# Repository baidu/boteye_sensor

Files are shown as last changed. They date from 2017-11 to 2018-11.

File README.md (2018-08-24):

boteye

## boteye_sensor ##
This repo contains hardware and firmware of Baidu boteye sensor.
**If you purchase the [hardware from Kinco Automation](http://www.kinco.cn/solution/detail?id=36&type=all)(a third party manufacturer), which is already loaded with the latest firmware, you can skip the following steps.**

## Hardware Introduction

Firmware supports three hardware versions: `XP`, `XP2`, and `XP3`.

## FX3 SDK Installation ##
  In order to compile, you need cypress FX3 sdk (http://www.cypress.com/documentation/software-and-drivers/ez-usb-fx3-software-development-kit).

  Download the sdk here http://www.cypress.com/file/221546

  You can get `fx3_firmware_linux.tar.gz` and `cyusb_linux_1.0.4.tar.gz`, then extract to root directory of this repo.
- Install arm gcc compiler

  ```bash
  sudo apt-get install gcc-arm-none-eabi
  ```

- Make sure your arm compiler is `arm-none-eabi-gcc version 4.8.2`

  ```bash
  arm-none-eabi-gcc --version
  ```
- Install gcc compiler

  ```bash
  sudo apt-get install build-essential
  ```

- Modify SDK config file

  - Configure build type in the file `cyfx3sdk/fw_build/fx3_fw/fx3_build_config.mak`

    Change `CYCONFOPT=fx3_debug` to `CYCONFOPT=fx3_release`

  - Configure the arm compiler info in the file `cyfx3sdk/fw_build/fx3_fw/fx3_armgcc_config.mak`

    Change `LDLIBS += ` section to your lib locations, most likely located in `/usr/arm-linux-gnueabi/lib/libc.a` and `/usr/lib/gcc/arm-none-eabi/4.8.2/libgcc.a`, and replace the default like this:
    ```bash
    The ARM toolchain location and the version are taken from environment variables
    LDLIBS  += \
    /usr/lib/arm-none-eabi/lib/libc.a \
    /usr/lib/gcc/arm-none-eabi/4.8.2/libgcc.a \

    EXEEXT		= elf
    ```
- Compile img format convert tools: `elf2img`

  To convert elf to img file, you need to compile `cyfx3sdk/util/elf2img/elf2img.c`
  ```bash
  cd cyfx3sdk/util/elf2img
  gcc elf2img.c -o elf2img -O3
  ```

## Compile Firmware ##
- If everything is all set, you can run `./build.sh` within `boteye_sensor/firmware`, which generates  `cyfxuvc.img`.

## FX3 Image Download Tool Install ##
- Install `libusb-dev`

  ```bash
  sudo apt-get install libusb-1.0-0-dev
  ```

- Install FX3 tools, please read the README in `./cyusb_linux_1.0.4`.

  ```bash
  cd cyusb_linux_1.0.4
  make
  chmod +x install.sh
  sudo ./install.sh
  ```
- If you find an error `qmake-qt4: command not found`, please install qt4 by running

  ```bash
  sudo apt-get install qt4-dev-tools qt4-doc qt4-qtconfig qt4-demos qt4-designer
  ```
- Add execute premission of `cyusb_linux`
  ```bash
  sudo chmod +x /usr/local/bin/cyusb_linux
  ```

- Add the following two lines to `~/.bashrc`, run `source ~/.bashrc`, and assign `CYUSB_ROOT` to the corresponding file path.

  ```bash
  export CYUSB_ROOT=~/Development/sensor/cyusb_linux_1.0.4/
  export LD_LIBRARY_PATH=/usr/local/lib/
  source ~/.bashrc
  ```
## Image Download ##

  - Use `cyusb_linux` to flash your img file to the board flash. If the sensor has an img on flash, it will
  go into auto-run mode with red LED blinking for 1s. If the sensor doesn't have an img on flash, the red LED will
  be always on.  We can use `./sensor/host_bin/spi_test` to erase the img on flash so that we can download a new one.
  - example: `./sensor/host_bin/spi_test /dev/video0`

## Firmware Tools ##
- There are two tools you can use in `firmware/host_bin`.
  - `spi_test`: erase flash
  - `version_test`: read hardware and software version.
- You can also install `luvcview` or other camera view tools to test the camera. However, you will most likely see green and red ghost images due to the custom formatting of the stereo raw images.

## About Version ##
- Hardware version:
  - You can use command `dmesg` to check USB `Product` attribute, it will show the hardware version.
  - Example: `Baidu_Robotics_vision_XP2`
- Software version:
  - You can also use `dmesg` to check USB `SeriaNumber` attribute, it will show the software version.
  - Example: `V0.3.7-839610e-commit` [version num - commit hash - commit/dirty]

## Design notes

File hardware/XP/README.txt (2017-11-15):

目录结构

├── README.txt
├── BOM                              //元件描述BOM
│   ├── XPCAM 1V1 PCB BOM.xls       //XP副板PCB物料
│   ├── XPIMU 1V1 PCB BOM.xls       //XP主板PCB物料
│
├── PCB file                         //PCB文件（可用DXP打开、编译）
│   ├── XPCAM_1V1.PCBDOC            //XP副板PCB文件
│   ├── XPIMU_1V1.PCBDOC            //XP主板PCB文件
│
├── schematic                        //原理文件（可用DXP打开、编译）
│   ├── XPCAM_1V1                  //XP副板原理图文件
│   │   ├── sch_Camera.SchDoc                 
│   │   ├── XPCAM_1V1.PrjPCB                  
│
│   ├── XPIMU_1V1                  //XP主板原理图文件   
│   │   ├── sch_Connet&IMU.SchDoc                 
│   │   ├── sch_CPU.SchDoc    
│   │   ├── sch_Power.SchDoc                
│   │   ├── sch_Top.SchDoc     
│   │   ├── sch_USB3.0.SchDoc                
│   │   ├── XPIMU_1V1.PrjPCB   
│
├── schematic&PCB PDF                //原理图、PCB的pdf格式
│   ├── PCB                         //XP PCB文件pdf格式
│   │   ├── XPCAM_1V1.pdf                
│   │   ├── XPIMU_1V1.pdf   
│
│   ├── schematic                  //XP 原理图文件pdf格式
│   │   ├── XPCAM_1V1_SCH.pdf                
│   │   ├── XPIMU_1V1_SCH.pdf      
└── 

硬件版本说明：

1.第一版，为主板连接双sensor的形式。

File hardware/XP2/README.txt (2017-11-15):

目录结构

├── README.txt
├── BOM                             //元件描述BOM
│   ├── XPCAM 1V4 PCB BOM.xls       //XP2副板PCB物料
│   ├── XPIAC 1V3 PCB BOM.xls       //XP2板PCB物料
│
├── PCB file                        //PCB文件（可用DXP打开、编译）
│   ├── XPCAM_1V4.PCBDOC            //XP2副板PCB文件
│   ├── XPIAC_1V3.PCBDOC            //XP2主板PCB文件
│
├── schematic                       //原理文件（可用DXP打开、编译）
│   ├── XPCAM_1V4                   //XP2副板原理图文件
│   │   ├── sch_Camera.SchDoc                 
│   │   ├── XPCAM_1V4.PrjPCB                  
│
│   ├── XPIAC_1V3                   //XP2主板原理图文件   
│   │   ├── sch_Camera.SchDoc 
│   │   ├── sch_Connet&IMU.SchDoc                 
│   │   ├── sch_CPU.SchDoc    
│   │   ├── sch_Power.SchDoc                
│   │   ├── sch_Top.SchDoc     
│   │   ├── sch_USB3.0.SchDoc                
│   │   ├── XPIAC_1V3.PrjPCB   
│
├── schematic&PCB PDF               //原理图、PCB的pdf格式
│   ├── PCB                         //XP2 PCB文件pdf格式
│   │   ├── XPCAM_1V4.pdf                
│   │   ├── XPIAC_1V3.pdf   
│
│   ├── schematic                   //XP2 原理图文件pdf格式
│   │   ├── XPCAM_1V4_SCH.pdf                
│   │   ├── XPIAC_1V3_SCH.pdf      
└── 

硬件版本说明：

1.优化XPCAM电源
2.将XPIMU与XPCAM合并为XPIAC
3.兼容彩色跟黑白

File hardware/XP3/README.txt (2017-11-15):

目录结构

├── README.txt
├── BOM                                //元件描述BOM
│   ├── XPCAM-C 1V4 PCB BOM.xls       //XP3副板PCB物料
│   ├── XPIAC-C 1V3 PCB BOM.xls       //XP3主板PCB物料
│
├── PCB file                           //PCB文件（可用DXP打开、编译）
│   ├── XPCAM-C_1V4.PCBDOC            //XP3副板PCB文件
│   ├── XPIAC-C_1V3.PCBDOC            //XP3主板PCB文件
│
├── schematic                          //原理文件（可用DXP打开、编译）
│   ├── XPCAM-C_1V4                    //XP3副板原理图文件
│   │   ├── sch_Camera.SchDoc                 
│   │   ├── XPCAM-C_1V4.PrjPCB                  
│
│   ├── XPIAC-C_1V3                  //XP3主板原理图文件   
│   │   ├── sch_Camera.SchDoc 
│   │   ├── sch_Connet&IMU.SchDoc                 
│   │   ├── sch_CPU.SchDoc    
│   │   ├── sch_Power.SchDoc                
│   │   ├── sch_Top.SchDoc     
│   │   ├── sch_USB3.0.SchDoc                
│   │   ├── XPIAC-C_1V3.PrjPCB   
│
├── schematic&PCB PDF                //原理图、PCB的pdf格式
│   ├── PCB                         //XP3 PCB文件pdf格式
│   │   ├── XPCAM-C_1V4.pdf                
│   │   ├── XPIAC-C_1V3.pdf   
│
│   ├── schematic                  //XP3 原理图文件pdf格式
│   │   ├── XPCAM-C_1V4_SCH.pdf                
│   │   ├── XPIAC-C_1V3_SCH.pdf      
└── 

硬件版本说明：

1.优化XPCAM电源
2.将XPIMU与XPCAM合并为XPIAC
3.兼容彩色跟黑白

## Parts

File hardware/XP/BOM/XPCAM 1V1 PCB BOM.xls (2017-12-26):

电子产品零件表
 |  | 版本:XPCAM 1V1 PCB BOM V1.0
序号 | 物料代码 | 数量 | 元件位置 | 规格 | 用途 | 备注
1 | 4.2.03.0089 | 3 | C16,C17,C18 | 贴片电容 10nF/0402/50V/10% | PCB
2 | 4.2.03.0088 | 14 | C2,C3,C4,C7,C8, C11,C12,C15,C19,C20, C21,C25,C26,C36 | 贴片电容 0.1uF/0402/16V/10% | PCB
3 | 4.2.03.0096 | 7 | C5,C9,C13,C23,C27, C34,C42 | 贴片电容 1uF/0402/6.3V/10% | PCB
4 | 4.2.03.0095 | 4 | C6,C10,C14,C45 | 贴片电容 4.7uF/0402/6.3V/20% | PCB
5 | 4.2.03.0101 | 7 | C1,C24,C28,C31,C35, C43,C44 | 贴片电容 10uF/0805/25V/10% | PCB
6 | 4.2.02.0205 | 1 | R7 | 贴片电阻 0R/0402/1% | PCB
7 | 4.2.02.0220 | 1 | R3 | 贴片电阻 22R/0402/5% | PCB
8 | 4.2.02.0214 | 5 | R1,R2,R4,R5,R6 | 贴片电阻 10K/0402/1% | PCB
9 | 7.2.01.0411 | 3 | U2,U3,U4 | 降压芯片 TPS73533DRVR | PCB
10 | 7.2.01.0412 | 1 | U1 | 集成芯片 MT9V024IA7XTM | PCB
11 | 7.2.07.0382 | 1 | J1 | 接插端子 20525-030E-02 | PCB
12 | 7.2.06.0203 | 1 |  | PCB光板 | PCB

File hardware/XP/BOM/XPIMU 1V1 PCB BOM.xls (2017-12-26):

电子产品零件表
 |  | 版本:XPIMU 1V1 PCB BOM V1.0
料号 | 物料代码 | 数量 | 元件位置 | 规格 | 用途 | 备注
1 | 7.2.03.0153 | 2 | C49,C50 | 贴片电容 12pF/0402/50V/5% | PCB
2 | 4.2.03.0089 | 12 | C13,C16,C17,C22,C25, C27,C28,C94,C95,C96, C97,C98 | 贴片电容 10nF/0402/50V/10% | PCB
3 | 4.2.03.0088 | 34 | C1,C3,C4,C5,C6, C7,C8,C9,C10,C11, C12,C14,C15,C19,C21, C23,C24,C26,C29,C31, C33,C35,C37,C39,C40, C41,C42,C51,C52,C53, C54,C58,C59,C67 | 贴片电容 0.1uF/0402/16V/10% | PCB
4 | 7.2.03.0146 | 1 | C57 | 贴片电容 0.47uF/0402/6.3V/10% | PCB
5 | 4.2.03.0096 | 1 | C60 | 贴片电容 1uF/0402/6.3V/10% | PCB
6 | 4.2.03.0095 | 3 | C36,C55,C56 | 贴片电容 4.7uF/0402/6.3V/20% | PCB
7 | 7.2.03.0154 | 1 | C32 | 贴片电容 4.7uF/0805/25V/10% | PCB
8 | 4.2.03.0101 | 2 | C34,C43 | 贴片电容 10uF/0805/25V/10% | PCB
9 | 7.2.03.0144 | 4 | C2,C18,C20,C30 | 贴片电容 47uF/0805/6.3V/20% | PCB
10 | 4.2.02.0205 | 2 | R30,R57 | 贴片电阻 0R/0402/1% | PCB
11 | 4.2.02.0220 | 3 | R27,R34,R60 | 贴片电阻 22R/0402/5% | PCB
12 | 4.2.02.0208 | 2 | R6,R21 | 贴片电阻 200R/0402/1% | PCB
13 | 4.2.02.0218 | 6 | R5,R14,R58,R59,R67, R62 | 贴片电阻 1K/0402/1% | PCB
14 | 4.2.02.0209 | 1 | R18 | 贴片电阻 1.5K/0402/1% | PCB
15 | 4.2.02.0226 | 2 | R25,R26 | 贴片电阻 2.2K/0402/5% | PCB
16 | 4.2.02.0210 | 1 | R20 | 贴片电阻 6.04K/0402/1% | PCB
17 | 4.2.02.0217 | 20 | R1,R2,R3,R7,R8, R10,R11,R12,R15,R16, R17,R19,R28,R29,R31, R32,R33,R35,R36,R37 | 贴片电阻 4.7K/0402/1% | PCB
18 | 4.2.02.0214 | 3 | R9,R44，R63 | 贴片电阻 10K/0402/1% | PCB
19 | 4.2.02.0213 | 1 | R53 | 贴片电阻 30.1K/0402/1% | PCB
20 | 4.2.02.0233 | 3 | R4,R13,R56 | 贴片电阻 100K/0402/1% | PCB
21 | 7.2.05.0130 | 1 | LED1, | 发光二极管 红色/0805 | PCB
22 | 7.2.05.0123 | 2 | LED2,LED3 | 发光二极管 绿色/0805 | PCB
23 | 4.2.04.0507 | 3 | FB1,FB2,FB3 | 磁珠 600@100MHz | PCB
24 | 7.2.08.0222 | 1 | U14 | 27M晶振 XTAL-3225 | PCB
25 | 7.2.08.0223 | 1 | U7 | 32.768K晶振 XTAL-3225 | PCB
26 | 7.2.08.0224 | 1 | Y1 | 19.2M晶振 XTAL_3225 | PCB
27 | 7.2.01.0413 | 1 | U9 | 陀螺仪芯片 ICM-20608-G | PCB
28 | 7.2.01.0414 | 1 | U13 | 降压芯片 AS1364-BTDT-AD | PCB
29 | 7.2.05.1005 | 3 | Q1,Q2,Q3 | NPN三极管 BC817 | PCB
30 | 7.2.08.0049 | 1 | U6 | 贴片保险丝 SP3010-04UTG | PCB
31 | 7.2.01.0415 | 1 | U4 | 降压芯片TPS74801DRCR | PCB
32 | 7.2.01.0416 | 1 | U2 | EEPROM芯片 M25P40-VMN3TPB | PCB
33 | 7.2.01.0417 | 1 | U1 | USB控制器 CYUSB3014 | PCB
34 | 7.2.07.1069 | 1 | J1 | USB3.0插头USB3_MICROB | PCB
35 | 7.2.07.0382 | 2 | J5,J6 | 接插端子 20525-030E-02C | PCB
36 | 7.2.06.0204 | 1 |  | PCB光板 | PCB

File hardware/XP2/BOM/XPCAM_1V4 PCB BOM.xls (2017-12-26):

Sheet: Read me
删除R38,C65更改为4.2.03.0095

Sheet: 170504
电子产品零件表
 |  | 版本:XPCAM 1V4 PCB BOM V1.0
序号 | 物料代码 | 数量 | 元件位置 | 元件描述 | 用途 | 备注
1 | 4.2.03.0104 | 1 | C85 | 贴片电容 1nF/0402/50V/10% | PCB
2 | 4.2.03.0089 | 2 | C81,C84 | 贴片电容 10nF/0402/50V/10% | PCB
3 | 4.2.03.0088 | 10 | C46,C47,C48,C61,C62, C66,C77,C78,C82,C83 | 贴片电容 0.1uF/0402/16V/10% | PCB
4 | 4.2.03.0095 | 7 | C44,C52,C63,C65,C70,C76, C79 | 贴片电容 4.7uF/0402/6.3V/20% | PCB
5 | 4.2.03.0101 | 4 | C39,C45,C64,C71 | 贴片电容 10uF/0805/25V/10% | PCB
6 | 4.2.02.0220 | 1 | R24 | 贴片电阻 22R/0402/5% | PCB
7 | 4.2.02.0214 | 5 | R23,R39,R40,R41,R42 | 贴片电阻 10K/0402/1% | PCB
8 | 7.2.04.0005 | 1 | L1 | 贴片电感 10uH/0805/10% | PCB
9 | 7.2.01.0411 | 1 | U5 | 降压芯片 TPS73533DRVR | PCB
10 | 7.2.01.0412 | 1 | U1 | 集成芯片 MT9V024IA7XTM | PCB
11 | 7.2.07.0382 | 1 | J1 | 接插端子 20525-030E-02 | PCB
12 | 7.2.06.0224 | 1 |  | PCB光板 | PCB

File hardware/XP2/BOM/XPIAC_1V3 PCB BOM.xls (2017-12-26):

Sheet: Read me
更改说明

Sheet: 171017
电子产品零件表
 |  | 版本:XPIAC 1V3 PCB BOM V1.0
料号 | 物料代码 | 数量 | 元件位置 | 元件描述 | 用途 | 备注
1 | 4.2.03.0104 | 1 | C85 | 贴片电容 1nF/0402/50V/10% | PCB
2 | 7.2.03.0153 | 2 | C49,C50 | 贴片电容 12pF/0402/50V/5% | PCB
3 | 4.2.03.0089 | 10 | C13,C16,C17,C22,C27, C81,C94,C95,C97,C98 | 贴片电容 10nF/0402/50V/10% | PCB
4 | 4.2.03.0088 | 40 | C1,C3,C4,C5,C6,C7, C8,C9,C10,C11,C12, C14,C15,C19,C21,C23, C24,C26,C29,C31,C33, C35,C37,C40,C41,C42, C46,C48,C51,C53,C58, C59,C61,C66,C68,C69, C77,C78,C82,C86 | 贴片电容 0.1uF/0402/16V/10% | PCB
5 | 7.2.03.0146 | 1 | C57 | 贴片电容 0.47uF/0402/6.3V/10% | PCB
6 | 4.2.03.0095 | 13 | C25,C28,C36,C44,C52, C54,C55,C56,C60,C63, C70,C76,C79 | 贴片电容 4.7uF/0402/6.3V/20% | PCB
7 | 4.2.03.0101 | 6 | C32,C34,C39,C43,C45, C64 | 贴片电容 10uF/0805/25V/10% | PCB
8 | 4.2.03.0094 | 4 | C2,C18,C20,C30 | 贴片电容 47uF/0805/6.3V/20% | PCB
9 | 7.2.04.0086 | 1 | L2 | 贴片电感 100uH/600mA | PCB
10 | 7.2.04.0005 | 1 | L1 | 贴片电感 10uH/0805 | PCB
11 | 4.2.02.0205 | 2 | R30,R57 | 贴片电阻 0R/0402/1% | PCB
12 | 4.2.02.0220 | 4 | R22,R24,R27,R60 | 贴片电阻 22R/0402/5% | PCB
13 | 4.2.02.0208 | 2 | R6,R21 | 贴片电阻 200R/0402/1% | PCB
14 | 4.2.02.0218 | 7 | R5,R14,R58,R59,R62, R63,R67 | 贴片电阻 1K/0402/1% | PCB
15 | 4.2.02.0209 | 1 | R18 | 贴片电阻 1.5K/0402/1% | PCB
16 | 4.2.02.0226 | 2 | R25,R26 | 贴片电阻 2.2K/0402/5% | PCB
17 | 4.2.02.0210 | 1 | R20 | 贴片电阻 6.04K/0402/1% | PCB
18 | 4.2.02.0217 | 12 | R1,R2,R3,R11,R12, R15,R16,R17,R19,R29, R31,R32 | 贴片电阻 4.7K/0402/1% | PCB
19 | 4.2.02.0214 | 7 | R9,R23,R39,R40,R41, R42,R44 | 贴片电阻 10K/0402/1% | PCB
20 | 4.2.02.0213 | 1 | R53 | 贴片电阻 30.1K/0402/1% | PCB
21 | 4.2.02.0233 | 3 | R4,R13,R56 | 贴片电阻 100K/0402/1% | PCB
22 | 7.2.05.0130 | 1 | LED1 | 发光二极管 红色/0805 | PCB
23 | 4.2.04.0507 | 3 | FB1,FB2,FB3 | 磁珠 600@100MHz | PCB
24 | 7.2.08.0222 | 1 | Y2 | 27M晶振 XTAL-3225 | PCB
25 | 7.2.08.0223 | 1 | U7 | 32.768K晶振 XTAL-3225 | PCB
26 | 7.2.08.0224 | 1 | Y1 | 19.2M晶振 XTAL_3225 | PCB
27 | 7.2.01.0413 | 1 | U9 | 陀螺仪芯片 ICM-20608-G | PCB
28 | 7.2.01.0414 | 1 | U13 | 降压芯片 AS1364-BTDT-AD | PCB
29 | 7.2.05.1005 | 4 | Q1,Q2,Q3,Q4 | NPN三极管 BC817 | PCB
30 | 7.2.08.0139 | 2 | S1,S2 | 贴片按键 2P | PCB
31 | 7.2.08.0049 | 1 | U6 | 贴片保险丝 SP3010-04UTG | PCB
32 | 7.2.01.0415 | 1 | U4 | 降压芯片 TPS74801DRCR | PCB
33 | 7.2.01.0416 | 1 | U2 | EEPROM芯片 M25P40-VMN3TPB | PCB
34 | 7.2.01.0417 | 1 | U1 | USB控制器 CYUSB3014 | PCB
35 | 7.2.07.1076 | 1 | J1 | USB3.0插头USB3_MICROB | PCB
36 | 7.2.07.0192 | 1 | P1 | uart接插端子 A1252MV-04P | PCB
37 | 7.2.07.0382 | 1 | J6 | 接插端子 20525-030E-02C | PCB
38 | 7.2.01.0411 | 1 | U5 | 降压芯片 TPS73533DRVR | PCB
39 | 7.2.01.0412 | 1 | U8 | 集成芯片 MT9V024IA7XTM | PCB
40 | 7.2.06.0236 | 1 |  | PCB光板 | PCB

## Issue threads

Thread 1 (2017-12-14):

可以把 GPIF II 工程代码也上传吗

cudnn, 2017-12-14:
我看了固件里 cyfxgpif2config.h 文件修改很多，能把 GPIF II 的有关文件也上传吗？

zhouryGitHub, 2017-12-19:
Our project is modified based on old version of  sample code cyfxuvc.  Now I am working to sync latest version . after finish it . gprif II file will upload.

cudnn, 2018-01-05:
Thanks very much! 你能看懂中文啊，太好了！我看了pcb布线也有一点疑问，XP2之后，fx3与mt9v034之间的信号使用了很多蛇形布线，这是不是为了实现信号线的等长？如果是，那么两个摄像头到fx3的距离也要等长吧？因为他们使用同一个时钟！所以还是建议两个摄像头分别做，并且时钟发生器放买主板上，到两点摄像头的距离也等长！

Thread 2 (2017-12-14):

GPIF II  project is  missing

cudnn, 2017-12-14:
When I try to load the GPIF II designer file,i find ImageSensorInterface.cyfx and gpif2model.xml gpif2timingsimulation.xml gpif2view.xml is  missing 。

zhouryGitHub, 2017-12-19:
Our project is modified based on old version of  sample code cyfxuvc.  Now I am working to sync latest version . After finish it . gprif II file will upload.

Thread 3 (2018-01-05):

cmos和fx3布线的疑问

cudnn, 2018-01-05:
我看了pcb布线也有一点疑问，XP2之后，fx3与mt9v034之间的信号使用了很多蛇形布线，这是不是为了实现信号线的等长？如果是，那么两个摄像头到fx3的距离也要等长吧？因为他们使用同一个时钟！所以还是建议两个摄像头分别做，并且时钟发生器放买主板上，到两点摄像头的距离也等长！

qinzengpan, 2018-01-05:
是实现等长。是否分开设计与性能要求、场景应用有关、制作成本等因素有关。你所说的，理论上对性能要求高的是可以到达更好的效果。但在结构设计上增加了复杂性以及在连接器上你要考虑使用怎么样的连接器和线的材料。所以最终如何设计，是综合考虑，就看你更在乎哪一点。

cudnn, 2018-01-11:
如果不分开，两个摄像头到主控的距离肯定不等长啊。因为使用一个时钟，所以两个摄像头到主控也应该是等长才行啊

qinzengpan, 2018-01-19:
由于板子尺寸、器件的密集型，对布局布线都会带来挑战性，我们的设计是尽量实现等长。及时没有使双目到主控芯片等长，在一些要求不高的场合也是可以允许的。当然，双目到主控的距离实现等长效果最好，你的观点也是没错的。

cudnn, 2018-01-29:
这个项目很好，持续关注中。

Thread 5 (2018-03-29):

为什么两个摄像头使用了两个晶振，不是应该共用一个时钟吗

cudnn, 2018-03-29:

zhouryGitHub, 2018-03-29:
请仔细看原理图，两个摄像头是用的同一个晶振

cudnn, 2018-03-30:
老师 有没有qq 微信啥的加个好友呗 weichat ardupilot4 qq 978917153

cudnn, 2018-03-30:
我再看看

cudnn, 2018-03-30:
我认真看了一， xp3版本中，在主板camera电路上有一个Y2 元件 hso531s 27MHZ，在独立的摄像头板也有一个    hso531s 27MHZ

zhouryGitHub, 2018-04-22:
在XP3 上 双目是共用一个 27M 晶振

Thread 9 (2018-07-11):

cyusb_linux Problem: No device found

VincentHFZ, 2018-07-11:
Try to use cyusb_linux tool to download img file, but the cyusb_linux tool can not find the device

zhouryGitHub, 2018-09-18:
please use ./spi_test to earse the flash on sensor, then you can download  the firmware use cyusb_linux

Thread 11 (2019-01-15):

firmware update problem

johnjin404, 2019-01-15:
你好，我在配置boteye标准版相机驱动时遇到了一些问题，发现它提示需要升级固件（当时检测到的版本是XP2S，在/dev/video1），后来我按照你们给出的提示在这里升级固件，但是这期间遇到两个我目前解决不了的问题。
1、我执行了 Image Download [https://github.com/baidu/boteye_sensor#image-download](url)之前的步骤，没有什么问题，但是在Image Download这步中，只有用命令`./spi_test  /dev/video1  E`没有错误反馈，但是l也没有led灯亮或者闪一秒。因为它没有错误反馈，我就接着执行下面的 version_test 程序，我的命令是`./version_test  /dev/video1`，它好像提示说Buffer size does not match control size。主要是搞不懂这两个程序的运行格式，希望有一个help功能。
2、后来我无意地把连接相机那一端的线拔了，再插上时，里面红灯一直亮着，而且现在/dev/video1也没有了，只剩下电脑自带的/dev/video0，请问怎样才能修复这个？谢谢

HansomHu, 2019-01-15:
问题1，update firmware请参考链接[https://github.com/baidu/boteye_sensor](url)，执行命令`./spi_test /dev/video*`的作用是擦除boteye的firmware，此时已经无法读取版本号，需要重新插拔usb数据线，然后运行`cyusb_linux`烧写新的firmware。
问题2，红灯一直亮，是因为firmware已经被擦除，pc自然检测不到这个video设备。
补充，更新完firmware后，可以通过`dmesg`命令看到boteye的信息，包括版本号。

johnjin404, 2019-01-15:
非常感谢！

Closed 2019-01-15.

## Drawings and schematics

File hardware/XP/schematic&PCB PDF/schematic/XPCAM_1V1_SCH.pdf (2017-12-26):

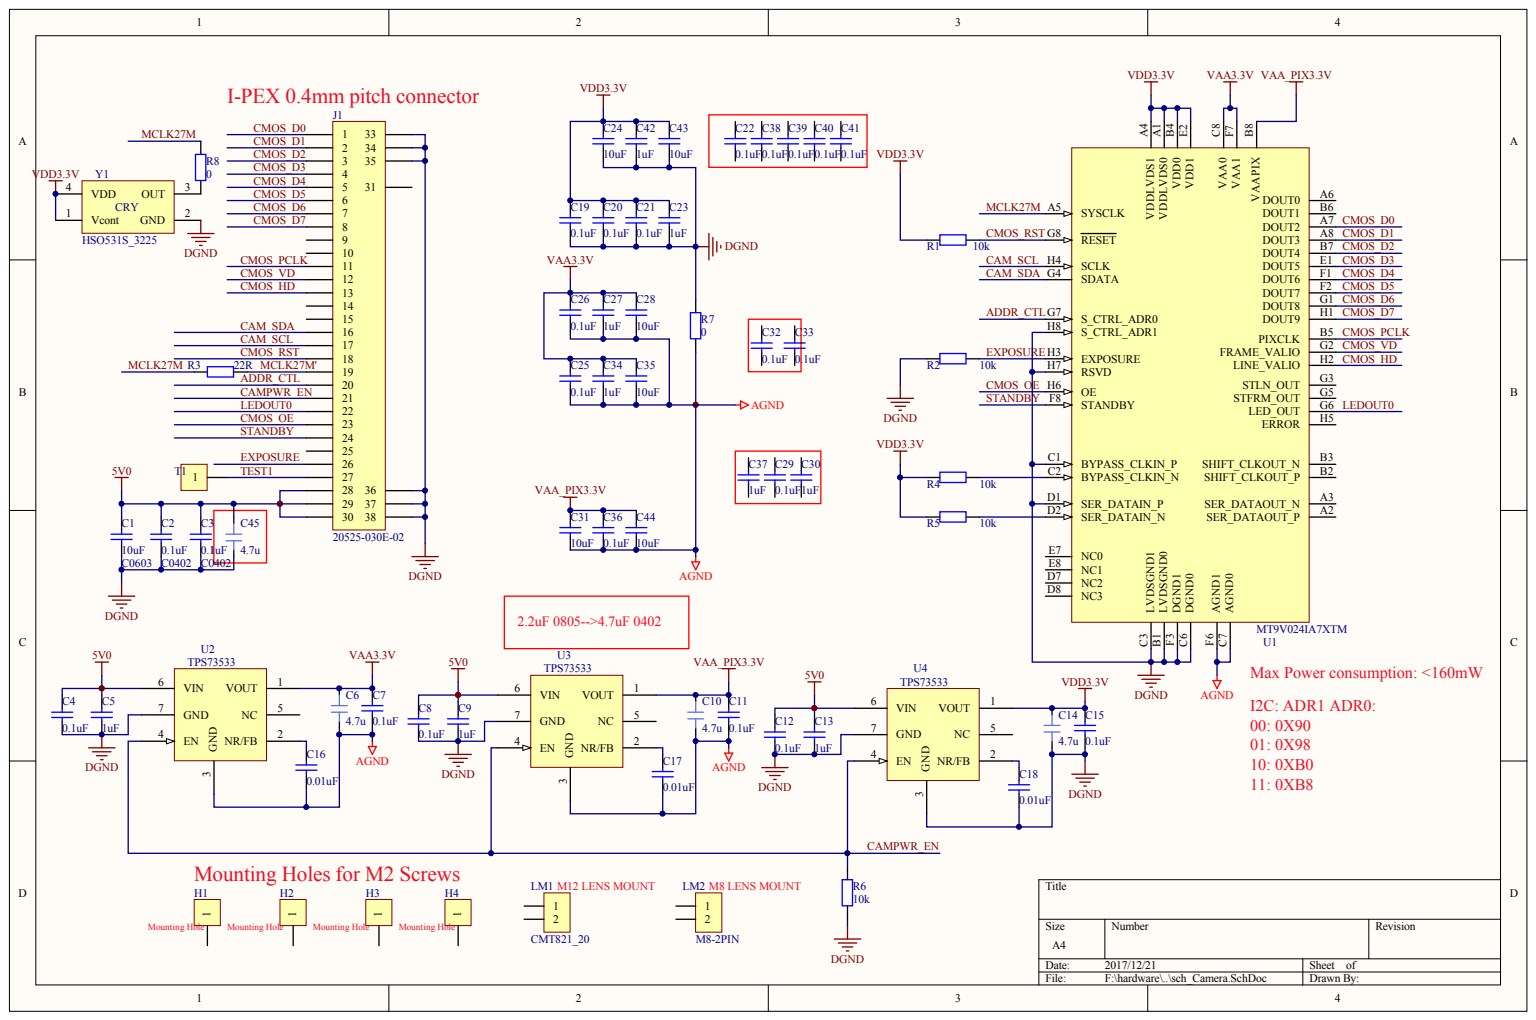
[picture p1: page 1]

Mounting Holes for M2 Screws

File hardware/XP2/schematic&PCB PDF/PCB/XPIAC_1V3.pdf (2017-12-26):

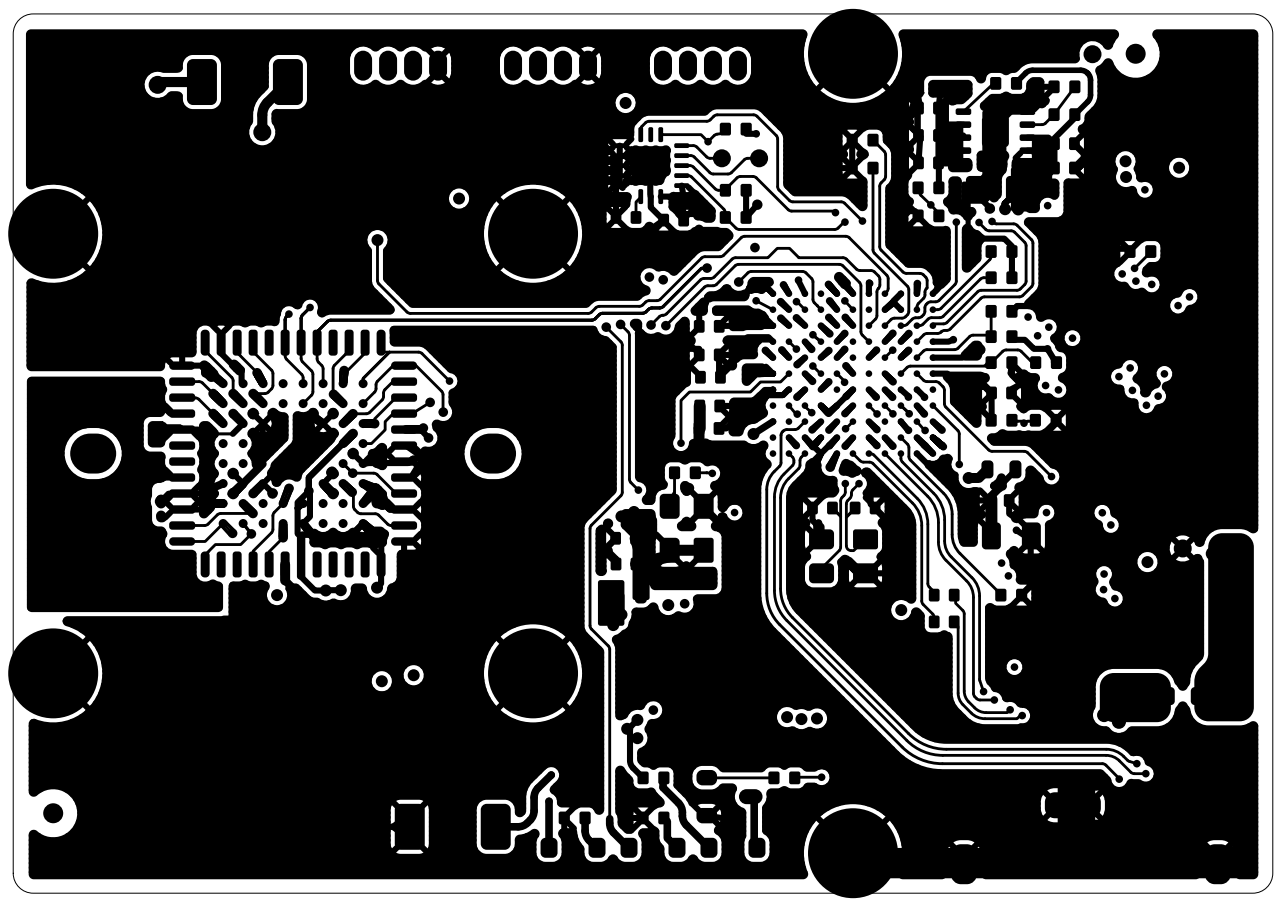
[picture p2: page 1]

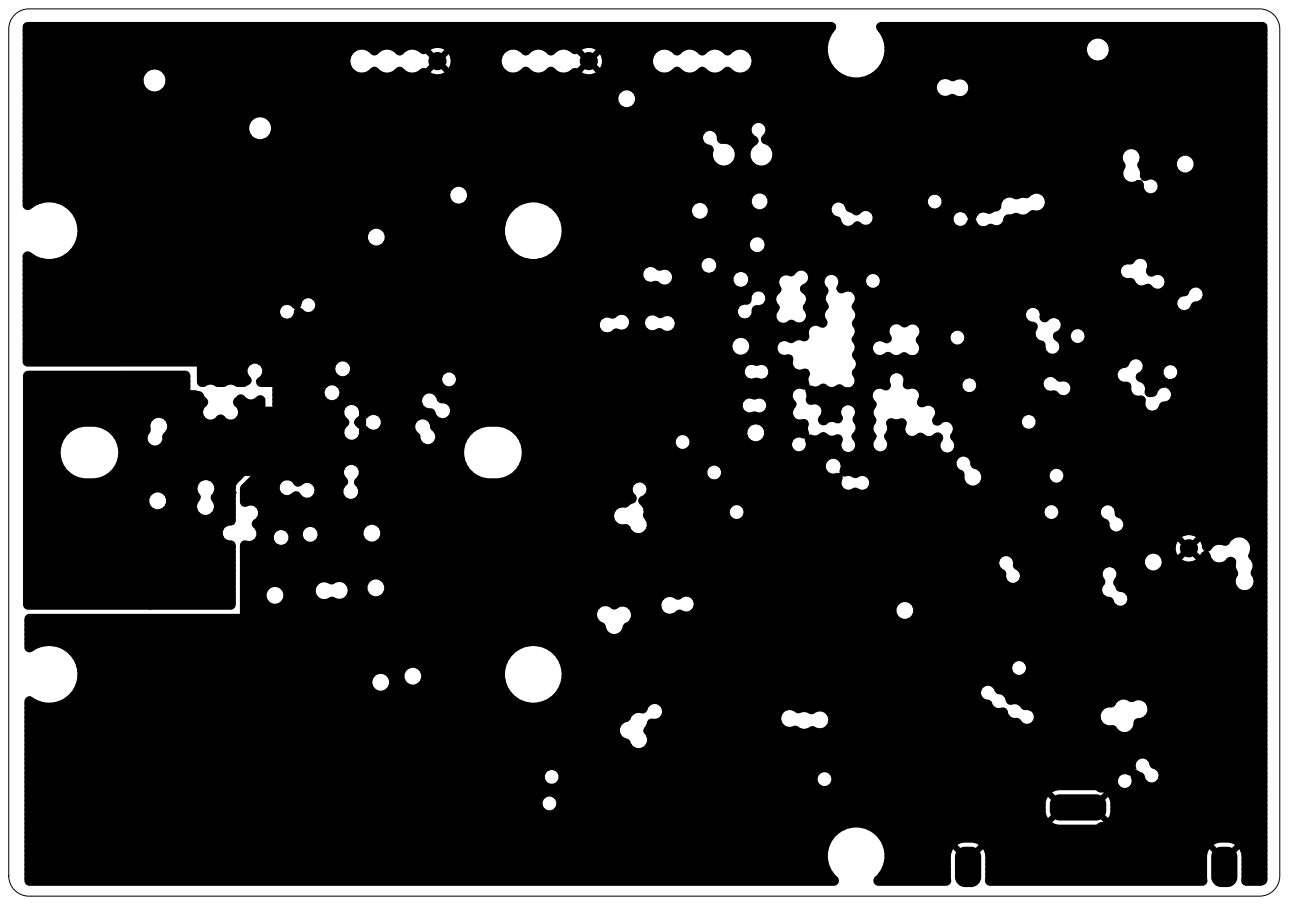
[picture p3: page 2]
H6H⁶x1; H4H⁴x1; GNDGNDx1; H1H¹x1; H2H²x1; H5H⁵x1; H3H³x1; 5V05V⁰x1; P1P¹x1 P¹x2 P¹x3 P¹x4; P2 P3P³x1 P³x2 P³x3 P³x4; P²x1 P²x2 P²x3 P²x4

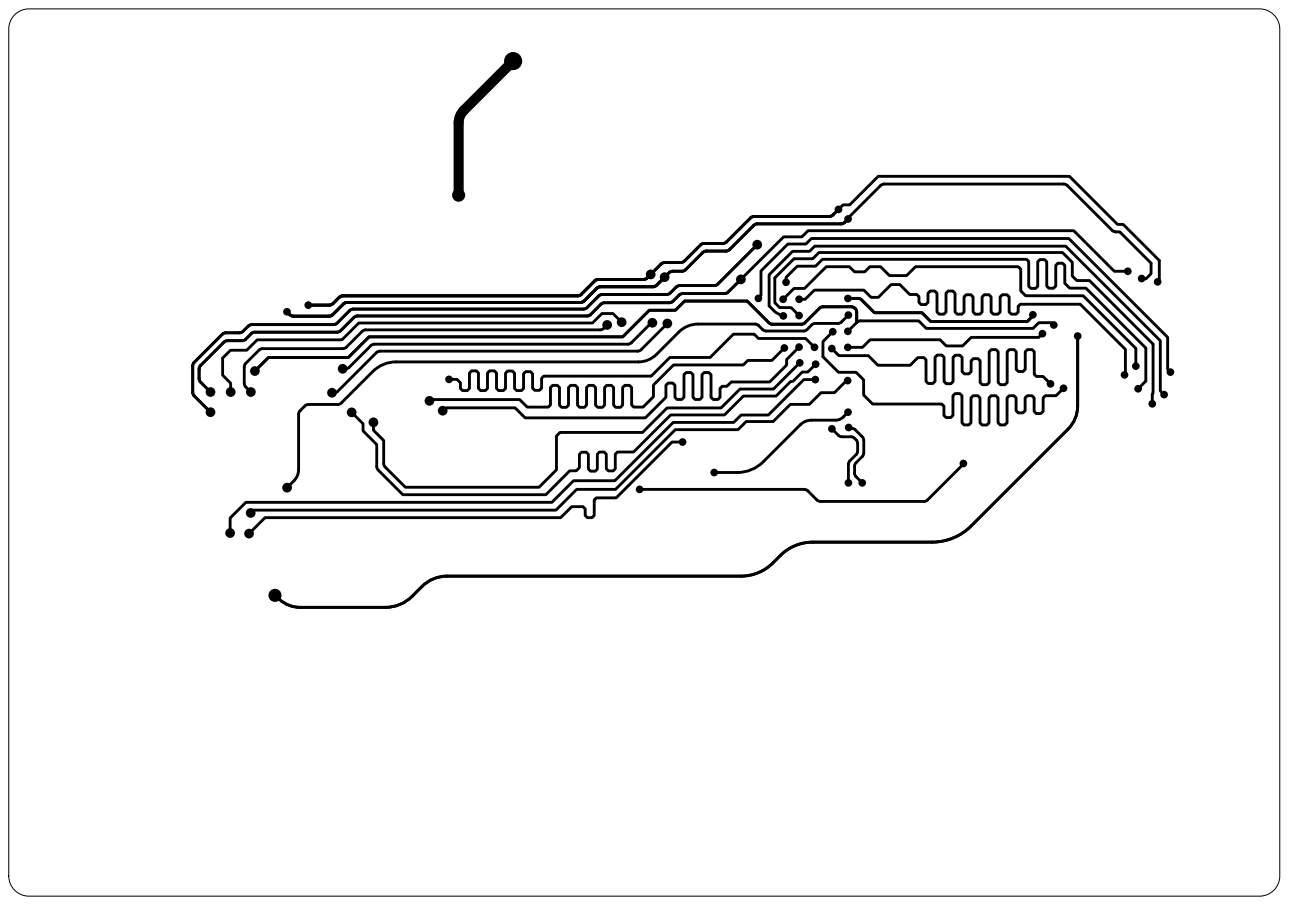
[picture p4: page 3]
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

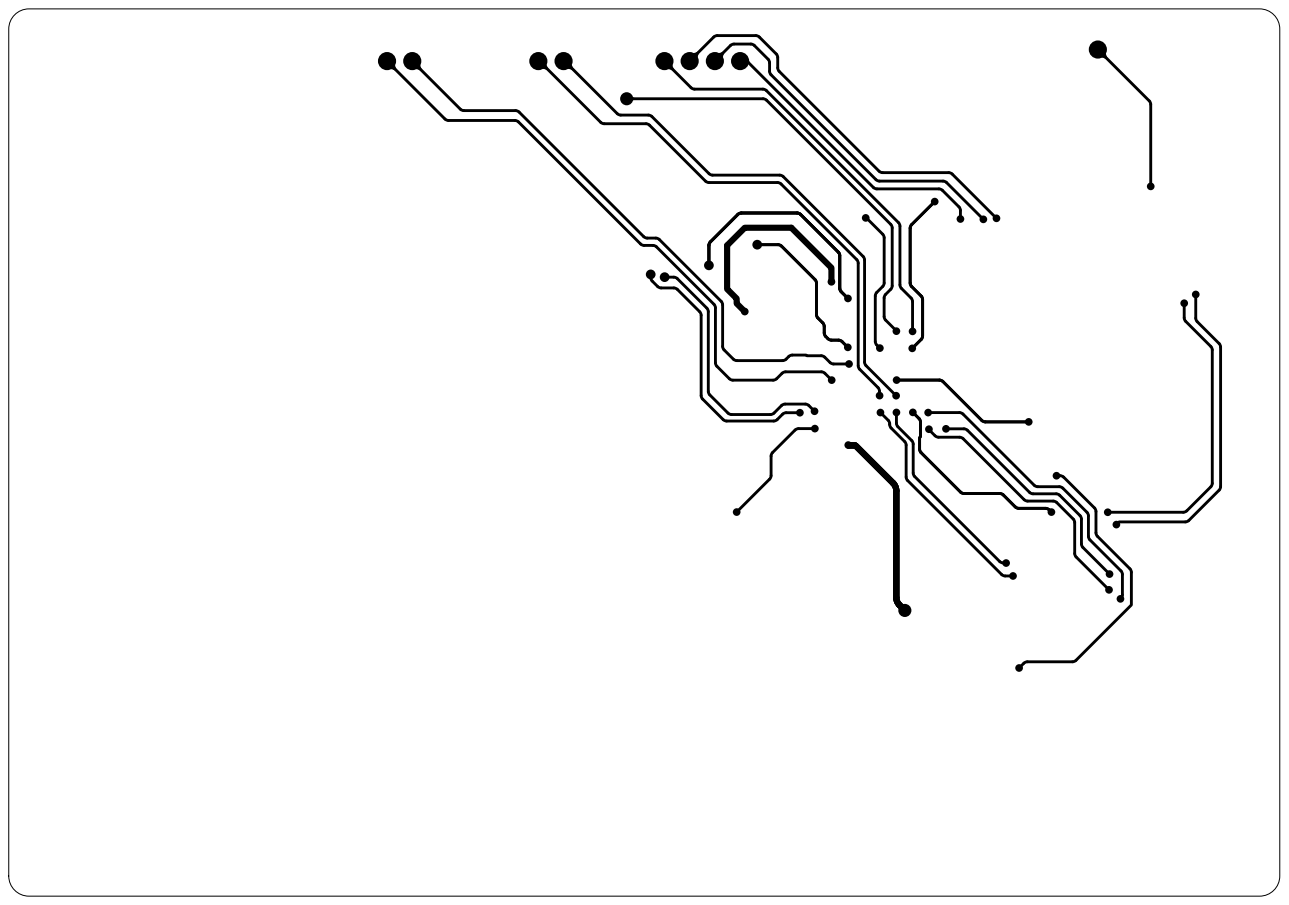
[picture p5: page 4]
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

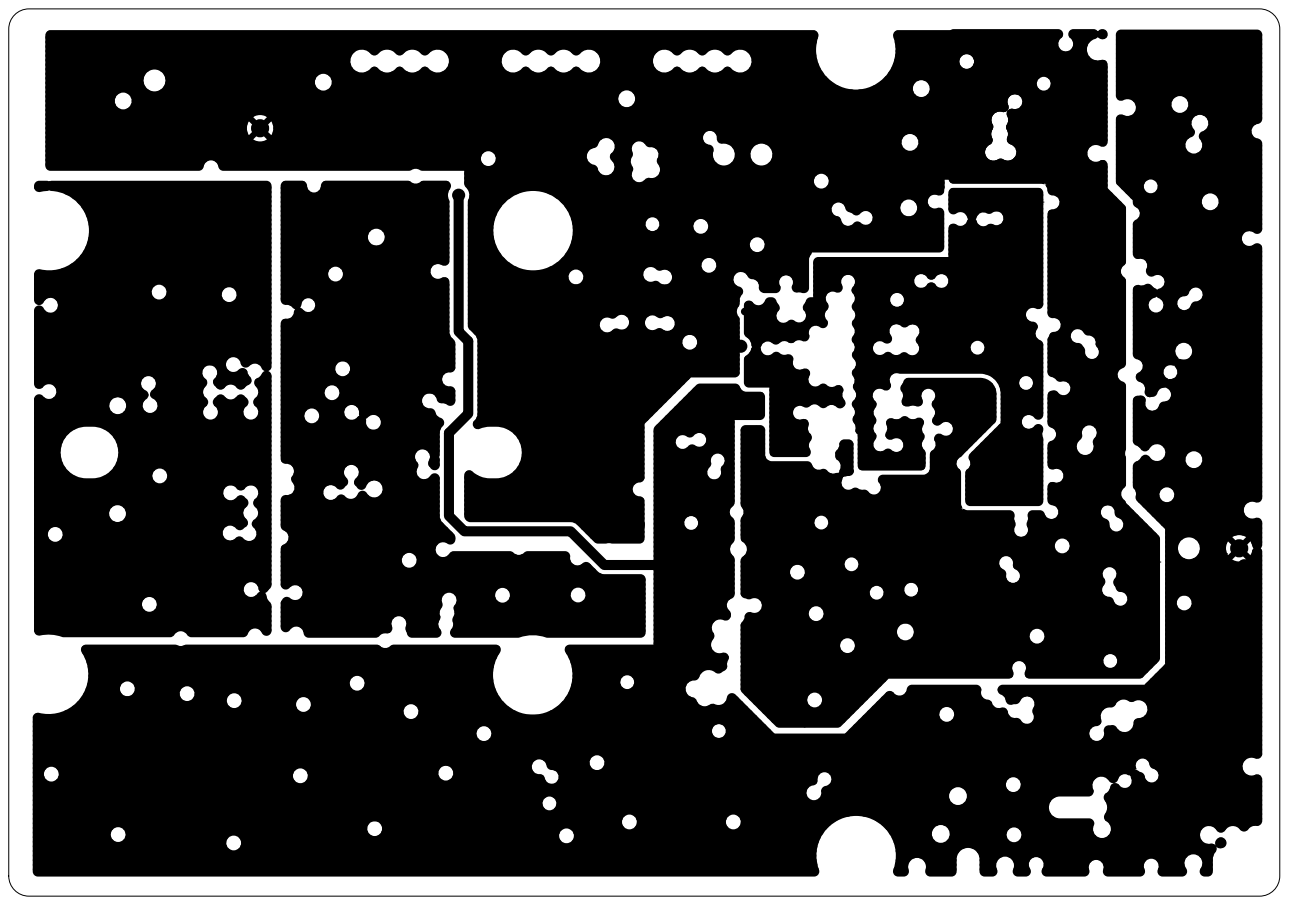
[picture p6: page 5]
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

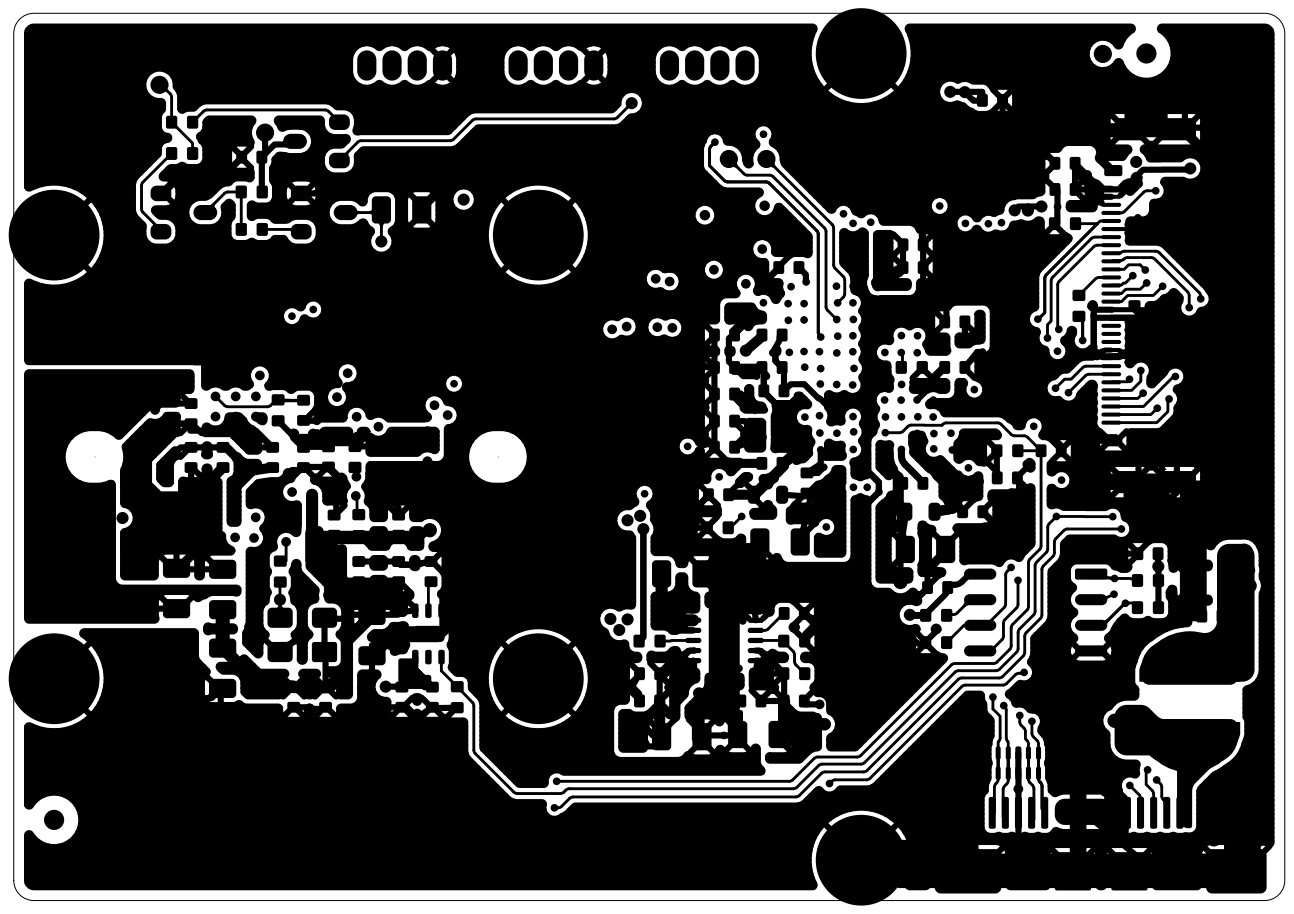
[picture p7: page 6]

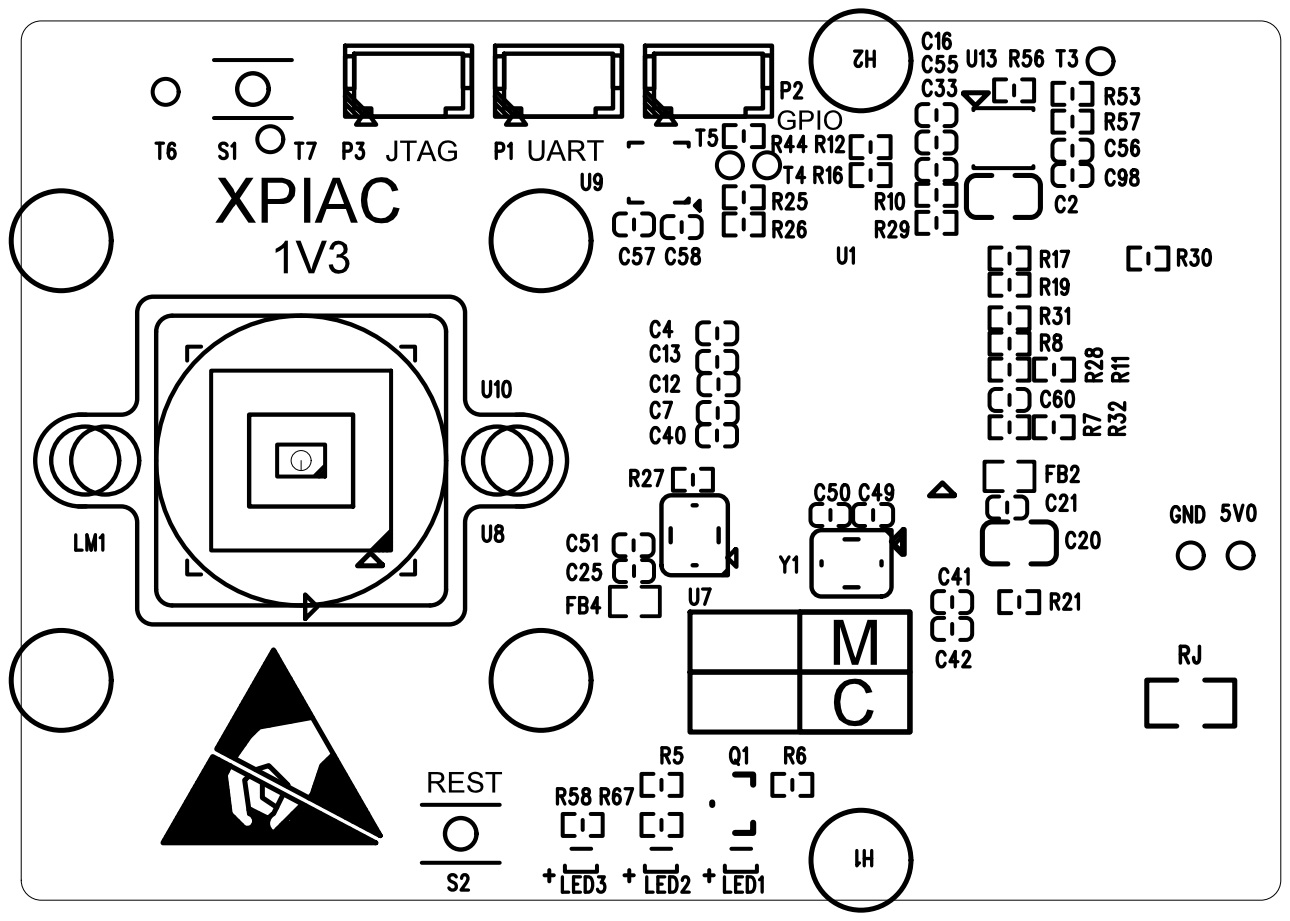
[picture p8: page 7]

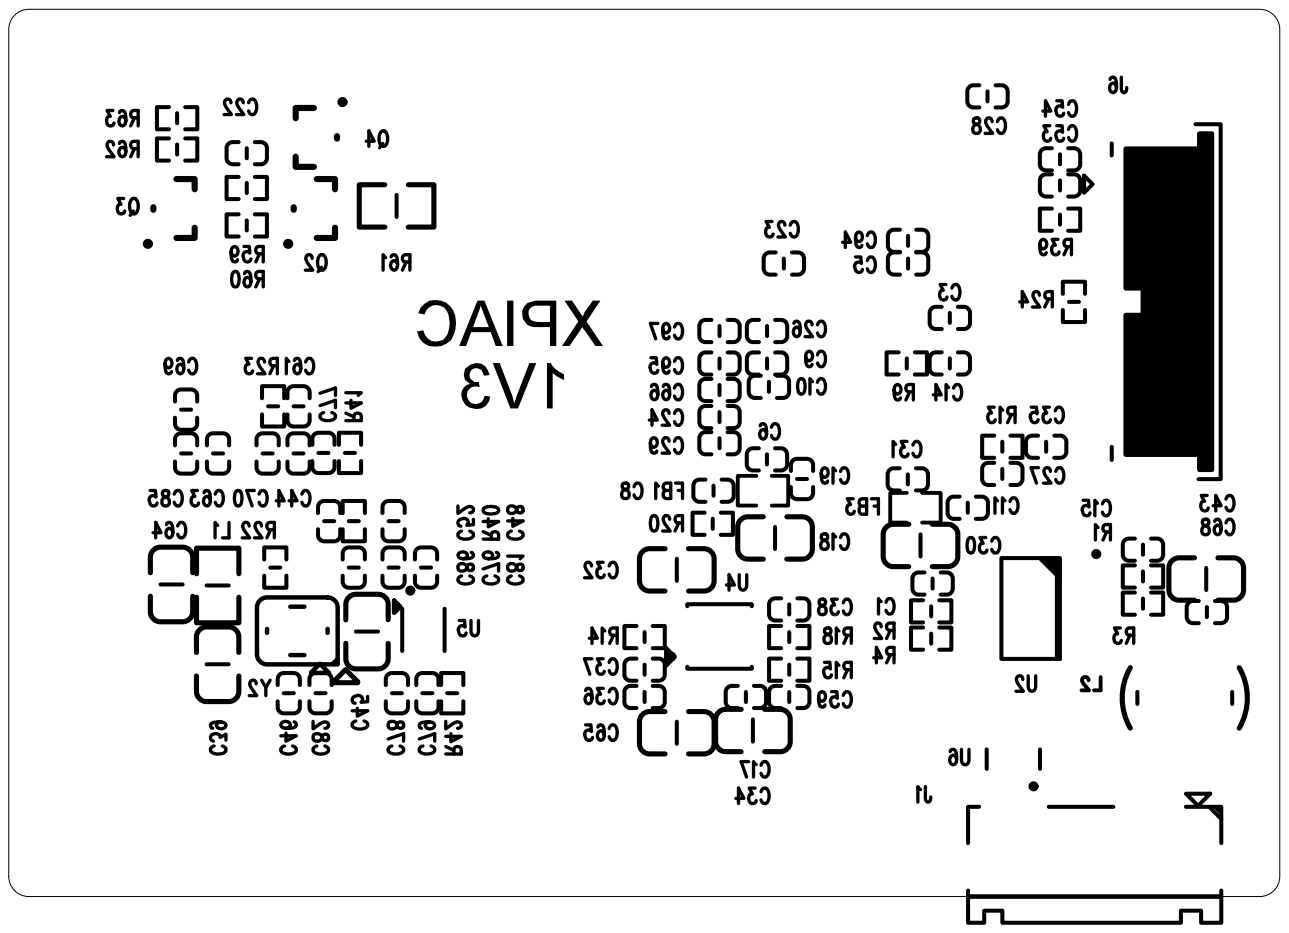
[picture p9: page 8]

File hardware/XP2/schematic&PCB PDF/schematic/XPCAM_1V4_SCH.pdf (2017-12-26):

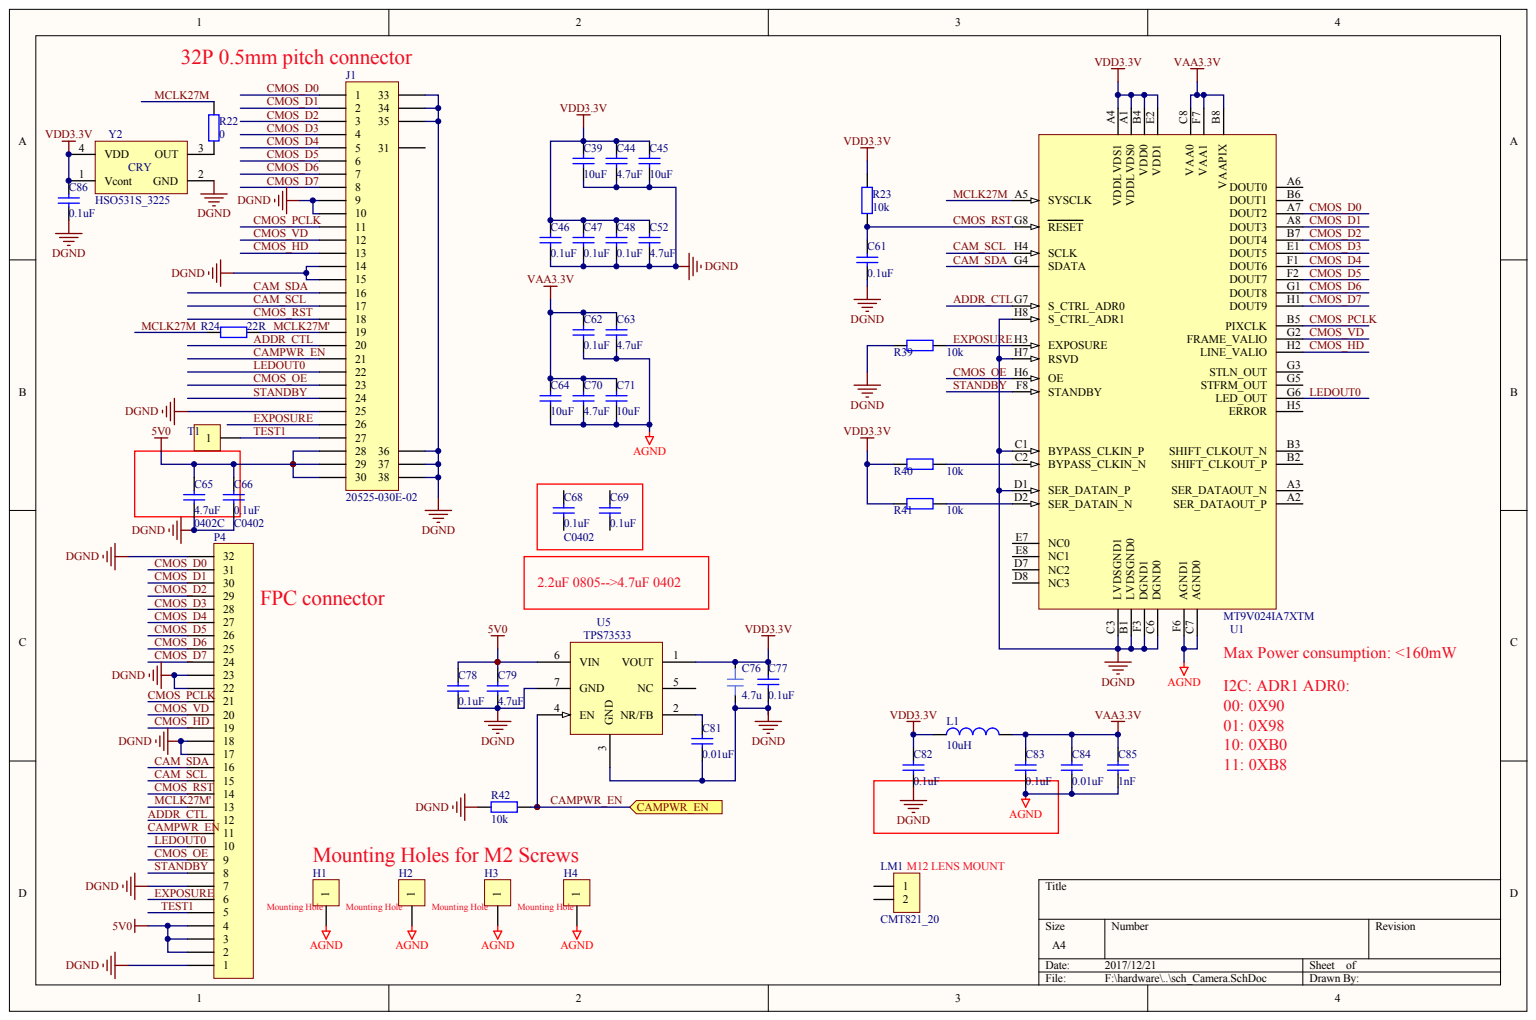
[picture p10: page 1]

m pitch connector Mounting Holes for M2 Screws 1

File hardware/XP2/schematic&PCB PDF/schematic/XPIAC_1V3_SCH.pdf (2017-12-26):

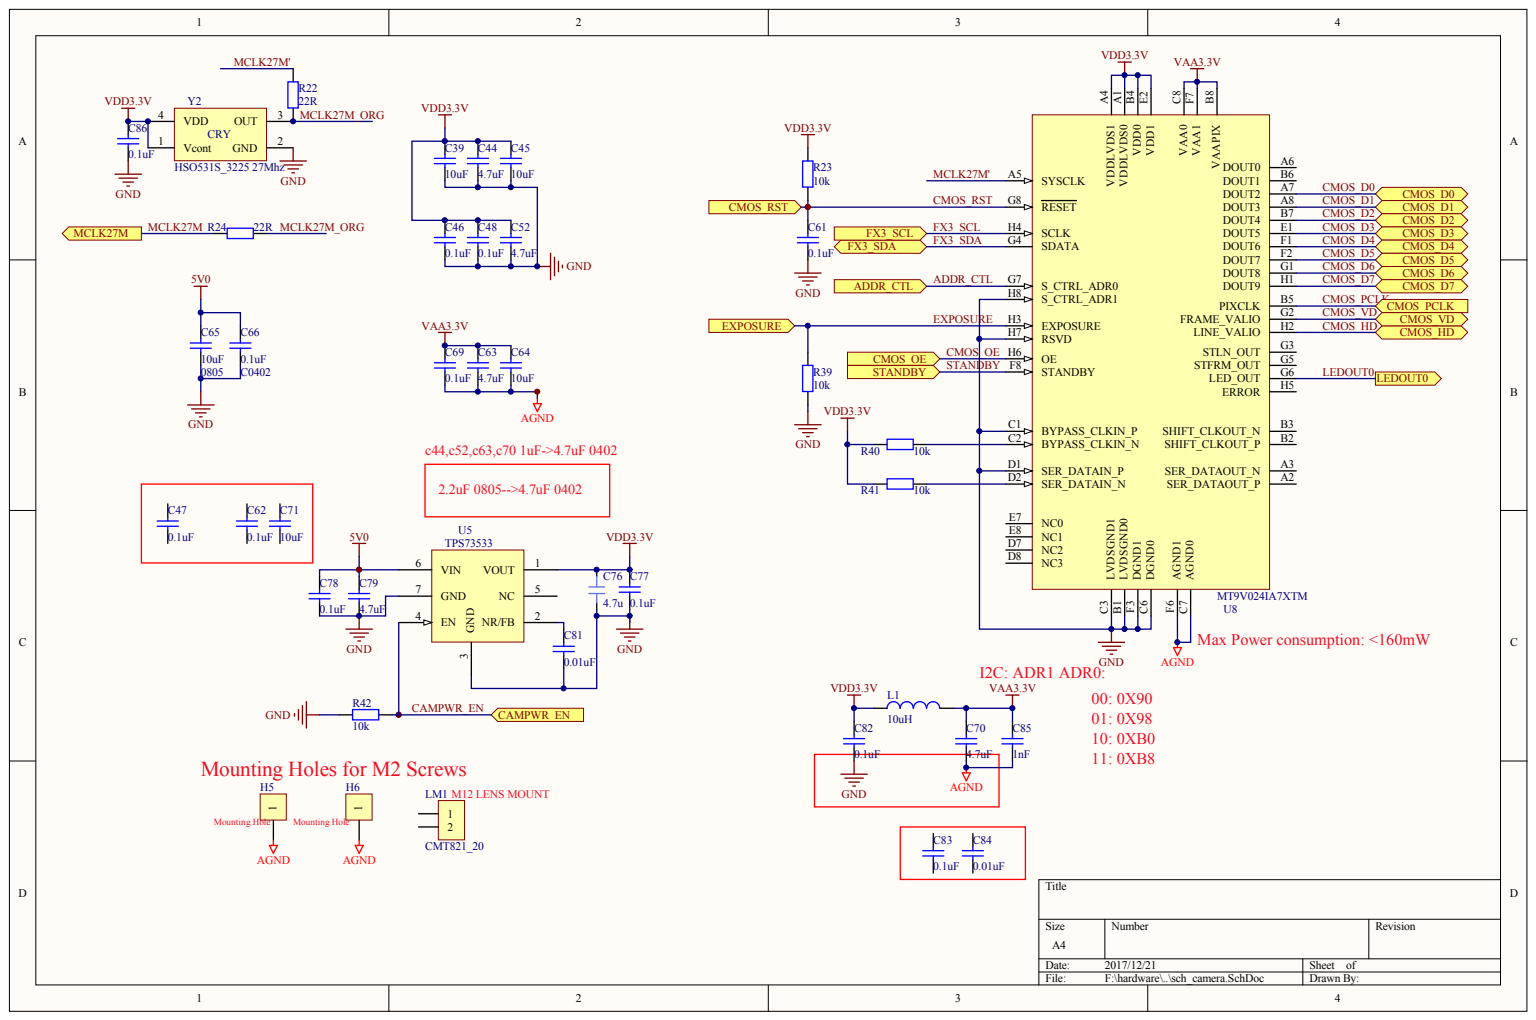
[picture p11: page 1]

11: 0XB8 Mounting Holes for M2 Screws

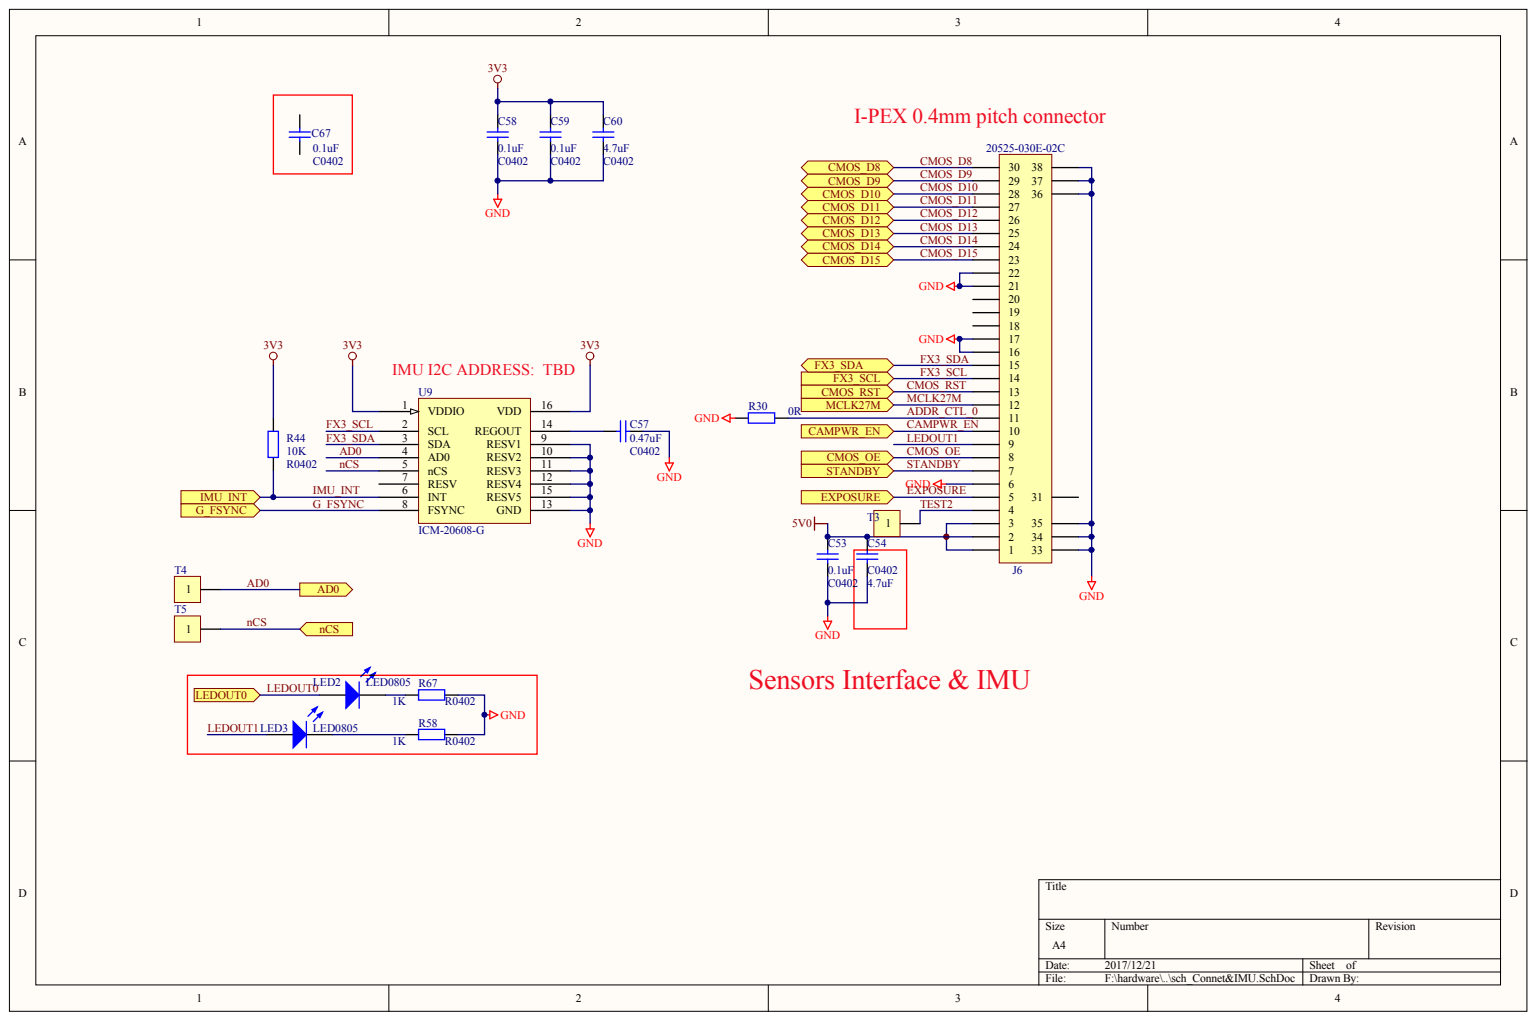
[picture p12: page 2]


SEC 2/ | 7

R3 | 4.7 K ROM _WPn 3


VDD3 L7

VDD5 F11
VDD6 L5

U3RXVDDQ A2
U3TXVDDQ B5

VSS2 L1
VSS3 E2
VSS4 L6
VSS5 D8
VSS6 G11
VSS7 L11
VSS8 K4
VSS9 L3
VSS10 K3


CMOS_RST
CMOS_D0 EXPOSURE
CMOS_D1 STANDBY
CMOS_D2 CAMPWR_EN
CMOS_D3 IMU_INT CMOS_D4 G_FSYNC CMOS_D5 AD0 CMOS_D6 nCS CMOS_D7 ADDR_CTL


The following signal pairs:
UTXP : UTXM
are designated as differential pairs.
All differential pairs are to have differential-mode
characteristic impedance of 90 0hm.
To the fullest resonable extent they should be
length-matched,and layer changes should be
minimized.

SS_RX_M | 4 4 | SS_RX_M
SS_TX_P | 1 1 2 2 | SS_TX_P
SS_TX_M | SS_TX_M | SS_RX_M | SSRXM A3 SSRXP A4

SS_DP | | NC A11
SS_DM

R_USB2 C8

R20 | 6.04K | R_USB3 B3

FSLC1 B4
FSLC2 E6

XTALIN C6

12pF | | XTALOUT C7

GND

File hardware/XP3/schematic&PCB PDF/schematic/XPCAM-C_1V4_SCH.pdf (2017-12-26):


m pitch connector Mounting Holes for M2 Screws 1

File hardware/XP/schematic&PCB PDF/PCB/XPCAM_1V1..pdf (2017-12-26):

# H1H¹x1

# H3H³x1

U1U¹xA¹ U¹xA² U¹xA³ U¹xA⁴ U¹xA⁵ U¹xA⁶ U¹xA⁷ U¹xA⁸; U¹xB¹ U¹xB² U¹xB³ U¹xB⁴ U¹xB⁵ U¹xB⁶ U¹xB⁷ U¹xB⁸; U¹xC¹ U¹xC² U¹xC³ U¹xC⁶ U¹xC⁷ U¹xC⁸; U¹xD¹ U¹xD² U¹xD⁷ U¹xD⁸; U¹xE¹ U¹xE² U¹xE⁷ U¹xE⁸; U¹xF1 U¹xF2 U¹xF3 U¹xF6 U¹xF7 U¹xF8; U¹xG¹ U¹xG² U¹xG³ U¹xG⁴ U¹xG⁵ U¹xG⁶ U¹xG⁷ U¹xG⁸; U¹xH¹ U¹xH² U¹xH³ U¹xH⁴ U¹xH⁵ U¹xH⁶ U¹xH⁷ U¹xH⁸; H2H²x1; H4H⁴x1; LM1LM¹x1; LM2LM²x1; M1M¹x1; M2M²x1; LM3LM³x1; LM4LM⁴x1

# H1H¹x1

# H3H³x1

H2H²x1; H4H⁴x1; LM1LM¹x1; LM2LM²x1; LM3LM³x1; LM4LM⁴x1

# H1H¹x1

# H3H³x1

H2H²x1; H4H⁴x1; LM1LM¹x1; LM2LM²x1; LM3LM³x1; LM4LM⁴x1

# H1H¹x1

# H3H³x1

H2H²x1; H4H⁴x1; LM1LM¹x1; LM2LM²x1; LM3LM³x1; LM4LM⁴x1

# H1H¹x1

# H3H³x1

H2H²x1; H4H⁴x1; LM1LM¹x1; LM2LM²x1; LM3LM³x1; LM4LM⁴x1

# C28 C²⁸x2 C²⁸x1

# H1H¹x1


# H1H¹x1

# H3H³x1

XPCAM 1V1; XPerception; H2H²x1; H4H⁴x1; LM1LM¹x1; LM2LM²x1; M1M¹x1; M2M²x1; LM3LM³x1; LM4LM⁴x1

U1U¹xA¹ U¹xA² U¹xA³ U¹xA⁴ U¹xA⁵ U¹xA⁶ U¹xA⁷ U¹xA⁸

# C28 C²⁸x2 C²⁸x1

# H1H¹x1


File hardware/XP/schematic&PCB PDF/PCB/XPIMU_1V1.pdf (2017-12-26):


H2H²x1; H1H¹x1; H4H⁴x1; H3H³x1

H2H²x1; H1H¹x1; H4H⁴x1; H3H³x1

H2H²x1; H1H¹x1; H4H⁴x1; H3H³x1

H2H²x1; H1H¹x1; H4H⁴x1; H3H³x1




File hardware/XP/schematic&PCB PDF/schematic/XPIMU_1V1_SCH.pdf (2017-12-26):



SEC 2/ | 7

R3 | 4.7 K ROM _WPn 3


VDD3 L7

VDD5 F11
VDD6 L5

U3RXVDDQ A2
U3TXVDDQ B5

VSS2 L1
VSS3 E2
VSS4 L6
VSS5 D8
VSS6 G11
VSS7 L11
VSS8 K4
VSS9 L3
VSS10 K3
VSS11 L2



The following signal pairs:
UTXP : UTXM
are designated as differential pairs.
All differential pairs are to have differential-mode
characteristic impedance of 90 0hm.
To the fullest resonable extent they should be
length-matched,and layer changes should be
minimized.

SS_RX_M | 4 4 | SS_RX_M
SS_TX_P | 1 1 2 2 | SS_TX_P
SS_TX_M | SS_TX_M | SS_RX_M | SSRXM A3 SSRXP A4

SS_DP | | NC A11
SS_DM

R_USB2 C8

R20 | 6.04K | R_USB3 B3

SEC 6/7

FSLC1 B4
FSLC2 E6

XTALIN C6

12pF | | XTALOUT C7

GND

CLKIN_32 D6

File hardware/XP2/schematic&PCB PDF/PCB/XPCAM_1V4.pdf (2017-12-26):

LM1 LM¹x1; U1 LM¹x2 U¹xA¹; U¹xA²; U¹xA³; U¹xA⁴; U¹xA⁵; U¹xA⁶; U¹xA⁷; U¹xA⁸ U¹xB¹; U¹xB²; U¹xB³; U¹xB⁴; U¹xB⁵; U¹xB⁶; U¹xB⁷; U¹xB⁸ U¹xC¹; U¹xC²; U¹xC³; U¹xC⁶; U¹xC⁷; U¹xC⁸ U¹xD¹; U¹xD²; U¹xD⁷; U¹xD⁸ U¹xE¹; U¹xE²; U¹xE⁷; U¹xE⁸ U¹xF1; U¹xF2; U¹xF3; U¹xF6; U¹xF7; U¹xF8 U¹xG¹; U¹xG²; U¹xG³; U¹xG⁴; U¹xG⁵; U¹xG⁶; U¹xG⁷; U¹xG⁸ U¹xH¹; U¹xH²; U¹xH³; U¹xH⁴; U¹xH⁵; U¹xH⁶; U¹xH⁷; U¹xH⁸; H1H¹x1; H2H²x1; H3H³x1; H4H⁴x1; M1M¹x1; M2M²x1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

H1H¹x1; H2H²x1; H3H³x1; H4H⁴x1

H1H¹x1; H2H²x1; H3H³x1; H4H⁴x1

H1H¹x1; H2H²x1; H3H³x1; H4H⁴x1

H1H¹x1; H2H²x1; H3H³x1; H4H⁴x1

C76C⁷⁶x1 C⁷⁶x2; R41R⁴¹x1 R⁴¹x2; R23R²³x1 R²³x2; C70C⁷⁰x1 C⁷⁰x2; C86C⁸⁶x1; R24R²⁴x1 R²⁴x2; C71C⁷¹x1 C⁷¹x2; C83C⁸³x1 C⁸³x2; C82C⁸²x1 C⁸²x2; R42R⁴²x1 R⁴²x2; C81C⁸¹x1 C⁸¹x2; C77C⁷⁷x1 C⁷⁷x2; C79C⁷⁹x1 C⁷⁹x2; C78C⁷⁸x1 C⁷⁸x2; C64C⁶⁴x1 C⁶⁴x2; C45C⁴⁵x1 C⁴⁵x2; H1H¹x1; H2H²x1; H3H³x1; H4H⁴x1; C66 C⁶⁶x1; C⁶⁶x2; C44C⁴⁴x1 C⁴⁴x2; C47C⁴⁷x1 C⁴⁷x2; C52C⁵²x1 C⁵²x2; C63C⁶³x1 C⁶³x2; C62C⁶²x1 C⁶²x2; C84C⁸⁴x1; R39R³⁹x1 R³⁹x2; R40R⁴⁰x1 R⁴⁰x2; C48C⁴⁸x1 C⁴⁸x2; M1M¹x1; M2M²x1; R22R²²x1 R²²x2; C85C⁸⁵x1 C⁸⁵x2; U5U⁵x3; U⁵x2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

XPCAM; LM1 U8U1 LM¹x1; LM¹x2 U¹xA¹; U¹xA²; U¹xA³; U¹xA⁴; U¹xA⁵; U¹xA⁶; U¹xA⁷; U¹xA⁸ U¹xB¹; U¹xB²; U¹xB³; U¹xB⁴; U¹xB⁵; U¹xB⁶; U¹xB⁷; U¹xB⁸ U¹xC¹; U¹xC²; U¹xC³; U¹xC⁶; U¹xC⁷; U¹xC⁸ U¹xD¹; U¹xD²; U¹xD⁷; U¹xD⁸ U¹xE¹; U¹xE²; U¹xE⁷; U¹xE⁸ U¹xF1; U¹xF2; U¹xF3; U¹xF6; U¹xF7; U¹xF8 U¹xG¹; U¹xG²; U¹xG³; U¹xG⁴; U¹xG⁵; U¹xG⁶; U¹xG⁷; U¹xG⁸ U¹xH¹; U¹xH²; U¹xH³; U¹xH⁴; U¹xH⁵; U¹xH⁶; U¹xH⁷; U¹xH⁸; H1H¹x1; H2H²x1; H3H³x1; H4H⁴x1; M1M¹x1; M2M²x1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


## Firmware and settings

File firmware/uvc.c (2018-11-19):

/*
 ## Cypress FX3 Camera Kit Source file (uvc.c)
 ## ===========================
 ##
 ##  Copyright Cypress Semiconductor Corporation, 2010-2012,
 ##  All Rights Reserved
 ##  UNPUBLISHED, LICENSED SOFTWARE.
 ##
 ##  CONFIDENTIAL AND PROPRIETARY INFORMATION
 ##  WHICH IS THE PROPERTY OF CYPRESS.
 ##
 ##  Use of this file is governed
 ##  by the license agreement included in the file
 ##
 ##     <install>/license/license.txt
 ##
 ##  where <install> is the Cypress software
 ##  installation root directory path.
 ##
 ## ===========================
*/
#include <cyu3system.h>
#include <cyu3os.h>
#include <cyu3dma.h>
#include <cyu3error.h>
#include <cyu3usb.h>
#include <cyu3uart.h>
#include <cyu3gpif.h>
#include <cyu3i2c.h>
#include <cyu3gpio.h>
#include <cyu3pib.h>
#include <cyu3utils.h>

#include "include/uvc.h"
#include "include/i2c.h"
#include "include/camera_ptzcontrol.h"
#include "include/cyfxgpif2config.h"
#include "include/inv_icm20608.h"
#include "include/LI_USB30_SENSORs.h"
/*This is for LI-CAM-MT9V034 V1.3*/
#include "include/sensor_v034_raw.h"
#include "include/debug.h"
#include "include/xp_sensor_firmware_version.h"
#include "include/extension_unit.h"
#include "include/cyfxuvcdscr.h"
#include "include/fx3_bsp.h"
#include "include/kfifo.h"
#include "include/tlc59116.h"
#include "include/tlc59108.h"
#include "include/sensor_ar0141.h"

/* debug_level :control debug log messages print level
 * 0 bit set: show debug level log
 * 1 bit set: show messages level log
 * 2 bit set: show buff messages logging */
int debug_level = 0;
struct firmware_ctl_t firmware_ctrl_flag;
enum SensorType sensor_type;
/******************************************************************************
                                         Global Variables
 *****************************************************************************/
static int res_switch = 0;
static CyU3PThread   uvcAppThread;                      /* UVC video streaming thread. */
static CyU3PThread   uvcAppEP0Thread;                   /* UVC control request handling thread. */
static CyU3PThread   Datahandle_Thread;                 /* IMU or other Data handle thread. */
CyU3PEvent    glFxUVCEvent;                             /* Event group used to signal threads. */
CyU3PDmaMultiChannel glChHandleUVCStream;               /* DMA multi-channel handle. */
static CyBool_t glSuspendEnbl    = CyFalse;             /* Whether Suspend Mode is requested. */
static CyBool_t glTriggerSuspend = CyFalse;             /* Initiate suspend entry . */
static uint8_t  glWakeUpSrc      = 0;                   /* Wakeup source from Low Power State */
static uint8_t  glWakeUpPol      = 0;                   /* Wakeup polarity from Low Power State */
/* Current UVC control request fields. See USB specification for definition */
uint8_t  bmReqType, bRequest;
uint16_t wValue, wIndex, wLength;
/* Whether USB connection is active */
CyBool_t        isUsbConnected = CyFalse;
/* Current USB connection speed */
CyU3PUSBSpeed_t usbSpeed = CY_U3P_NOT_CONNECTED;
/* Whether a CLEAR_FEATURE (stop streaming) request has been received */
CyBool_t        clearFeatureRqtReceived = CyFalse;
/* Whether USB host has started streaming data */
CyBool_t        streamingStarted = CyFalse;
/* Whether the application is active or not */
CyBool_t        glIsApplnActive  = CyFalse;

#ifdef BACKFLOW_DETECT
/* Whether buffer overflow error is detected */
uint8_t back_flow_detected = 0;
#endif
/* Whether end of frame (FV) signal has been hit. */
static volatile CyBool_t hitFV = CyFalse;
/* Whether the GPIF init function has been called. */
static volatile CyBool_t gpif_initialized = CyFalse;
/* Count of buffers received and committed during the current video frame. */
static volatile uint16_t prodCount = 0, consCount = 0;
static volatile uint16_t underrunCnt = 0;

/* IMU Header are prefixed at the top of each frame as timestamp */
volatile char glIMUHeader[16] = {'0', '1', '2', '3', '4', '5', '6', '7', '8', '9',
                                 'A', 'B', 'C', 'D', 'E', 'F'};

#define IMU_POOL_LEN     640 * 2 - 4 - 17
static volatile CyBool_t addIMU = CyFalse;
static volatile CyBool_t readyIMU = CyFalse;
static uint8_t IMU_pool_buf[IMU_POOL_LEN] =  {0};
struct __kfifo  IMU_kfifo;
volatile CyBool_t IR_image_trigger = CyFalse;

/* UVC Probe Control Settings for a USB 3.0 connection. */
uint8_t glProbeCtrl[CY_FX_UVC_MAX_PROBE_SETTING] = {
    /* bmHint : no hit */
    0x00, 0x00,
    /* Use 1st Video format index */
    0x01,
    /* Use 1st Video frame index */
    0x01,
    /* Desired frame interval in the unit of 100ns: 30 fps */
    0x0A, 0x8B, 0x02, 0x00,    // 0x15, 0x16, 0x05, 0x00,  /* 60ps */
    /* Key frame rate in key frame/video frame units */
    0x00, 0x00,
    /* PFrame rate in PFrame / key frame units */
    0x00, 0x00,
    /* Compression quality control */
    0x00, 0x00,
    /* Window size for average bit rate */
    0x00, 0x00,
    /* Internal video streaming i/f latency in ms */
    0x00, 0x00,
    /* Max video frame size in bytes */
    0x00, 0x48, 0x3F, 0x00,
    /* No. of bytes device can rx in single payload = 16 KB */
    0x00, 0x40, 0x00, 0x00
  };

/* UVC Probe Control Setting for a USB 2.0 connection. */
uint8_t glProbeCtrl20[CY_FX_UVC_MAX_PROBE_SETTING] = {
    /* bmHint : no hit */
    0x00, 0x00,
    /* Use 1st Video format index */
    0x01,
    /* Use 1st Video frame index */
    0x01,
    /* Desired frame interval in the unit of 100ns: 15 fps */
    0x2A, 0x2C, 0x0A, 0x00,
    /* Key frame rate in key frame/video frame units */
    0x00, 0x00,
    /* PFrame rate in PFrame / key frame units */
    0x00, 0x00,
    /* Compression quality control */
    0x00, 0x00,
    /* Window size for average bit rate */
    0x00, 0x00,
    /* Internal video streaming i/f latency in ms */
    0x00, 0x00,
    /* Max video frame size in bytes */
    0x00, 0x60, 0x09, 0x00,
    /* No. of bytes device can rx in single payload = 16 KB */
    0x00, 0x40, 0x00, 0x00
  };

/** \brief Video Probe Commit Control
 *
 * This array is filled out when the host sends down the SET_CUR request
 */
static uint8_t glCommitCtrl[CY_FX_UVC_MAX_PROBE_SETTING_ALIGNED];

/* UVC Header to be prefixed at the top of each 16 KB video data buffer. */
uint8_t volatile glUVCHeader[CY_FX_UVC_MAX_HEADER] = {
    /* Header Length */
    0x0C,
    /* Bit field header field */
    0x8C,
    /* Presentation time stamp field */
    0x00, 0x00, 0x00, 0x00,
    /* Source clock reference field */
    0x00, 0x00, 0x00, 0x00, 0x00, 0x00
  };
/******************************************************************************
                                         Static Function
 *****************************************************************************/
static void usb_set_desc(void);
static void CyFxPowerManage(void);
/**
 *  @brief      Add the IMU packet header to the top of the specified DMA buffer.
 *  @param[in]  buffer_p    Buffer pointer.
 *  @return     no return.
 */
void CyFxUVCAddHeader_IMU(uint8_t *buffer_p) {
  uint32_t imu_fifo_len = 0;
  uint32_t imu_num = 0;
  if (!readyIMU) {
    CyU3PMemCopy(buffer_p, (uint8_t *)glIMUHeader, sizeof (glIMUHeader));
    return;
  }

  addIMU = CyFalse;
  /* IMU Burst from image data byte operation
  ------------------------------------------------------------------------------------------
  |Byte location|image timestamp|IMU flag|IMU num|Single IMU Data 0| ... |Single IMU Data N|
  ------------------------------------------------------------------------------------------
  |   Byte num  |      16       |    1   |   4   |        17       | ... |        17       |
  ------------------------------------------------------------------------------------------  
  IMU flag:0 -> this version of fimware don't support IMU burst from image.
           1 -> this version of frimwre support. 
  */
  /*NOTE: we remain last_imu at first 17 bytes to old vesion of tracking */
  CyU3PMemCopy(buffer_p, (uint8_t *)last_imu, sizeof (last_imu));
  /* update imu burst embed image flags */
  if (firmware_ctrl_flag.imu_from_image) {
    *(buffer_p + 16) = 1;
    CyU3PMutexGet(&(IMU_kfifo.lock), CYU3P_WAIT_FOREVER);
    imu_fifo_len = kfifo_used(&IMU_kfifo);
    if (imu_fifo_len >= IMU_BURST_LEN) {
      imu_num = imu_fifo_len / IMU_BURST_LEN;
      CyU3PMemCopy(buffer_p + IMU_BURST_LEN, (uint8_t *)(&imu_num), 4);
      kfifo_out(&IMU_kfifo, (void *)(buffer_p + IMU_BURST_LEN + 4), imu_fifo_len);
    }
    CyU3PMutexPut(&(IMU_kfifo.lock));
  }
  if ((sensor_type == XPIRL2 || sensor_type == XPIRL3 || sensor_type == XPIRL3_A) &&
      IR_image_trigger == CyFalse) {
    *(buffer_p + 0) = 'R';
    *(buffer_p + 1) = 'G';
    *(buffer_p + 2) = 'B';
  } else if  ((sensor_type == XPIRL2 || sensor_type == XPIRL3) && IR_image_trigger == CyTrue) {
    *(buffer_p + 0) = 'I';
    *(buffer_p + 1) = 'R';
    sensor_err("IR image\r\n");
    IR_image_trigger = CyFalse;
  }
  return;
}

/**
 *  @brief      Add the UVC packet header to the top of the specified DMA buffer.
 *  @param[in]  buffer_p    Buffer pointer.
 *  @param[in]  frameInd    EOF or normal frame indication
 *  @return     no return.
 */
void CyFxUVCAddHeader(uint8_t *buffer_p, uint8_t frameInd) {
  /* Copy header to buffer */
  CyU3PMemCopy(buffer_p, (uint8_t *)glUVCHeader, CY_FX_UVC_MAX_HEADER);

  /* The EOF flag needs to be set if this is the last packet for this video frame. */
  if (frameInd & CY_FX_UVC_HEADER_EOF) {
    buffer_p[1] |= CY_FX_UVC_HEADER_EOF;
  }
}

/* This function performs the operations for a Video Streaming Abort.
   This is called every time there is a USB reset, suspend or disconnect event.
 */
static void CyFxUVCApplnAbortHandler(void) {
  uint32_t flag;
  if (CyU3PEventGet(&glFxUVCEvent, CY_FX_UVC_STREAM_EVENT, CYU3P_EVENT_AND, \
                    &flag, CYU3P_NO_WAIT) == CY_U3P_SUCCESS) {
    sensor_dbg("video streaming abort!\r\n ");
    /* Clear the Video Stream Request Event */
    CyU3PEventSet(&glFxUVCEvent, ~(CY_FX_UVC_STREAM_EVENT), CYU3P_EVENT_AND);

    /* Set Video Stream Abort Event */
    CyU3PEventSet(&glFxUVCEvent, CY_FX_UVC_STREAM_ABORT_EVENT, CYU3P_EVENT_OR);
  }
}

/**
 *  @brief      This is the Callback function to handle the USB Events.
 *  @param[in]  evtype    Event type.
 *  @param[in]  evdata    Event data.
 *  @return     no return.
 */
static void UVC_USBEvent_CB(CyU3PUsbEventType_t evtype, uint16_t evdata) {
  switch (evtype) {
  /* USB Connect event */
  case CY_U3P_USB_EVENT_CONNECT:
    sensor_dbg("USB %s connect event detected\r\n", evdata == 1 ? "3.0" : "2.0");
    break;

  /* USB Set Configuration event. evData provides the configuration number selected by the host */
  case CY_U3P_USB_EVENT_SETCONF:
    glIsApplnActive = CyTrue;
    sensor_dbg("USB set Configuration evdata:0x%x\r\n", evdata);
    break;

  /* USB Reset event. evData indicates whether 3.0 or 2.0 connection*/
  case CY_U3P_USB_EVENT_RESET:
    sensor_dbg("USB %s Reset Detect\r\n", evdata == 1 ? "3.0" : "2.0");
    CyU3PGpifDisable(CyTrue);
    gpif_initialized = 0;
    streamingStarted = CyFalse;
    CyFxUVCApplnAbortHandler();
    glSuspendEnbl = CyFalse;
    break;

  /* USB Suspend event for both USB 2.0 and 3.0 connections. evData is not used */
  case CY_U3P_USB_EVENT_SUSPEND:
    sensor_dbg("USB SUSPEND event detected\r\n");
    CyU3PGpifDisable(CyTrue);
    gpif_initialized = 0;
    streamingStarted = CyFalse;
    CyFxUVCApplnAbortHandler();
    glSuspendEnbl = CyTrue;
    break;

  /* USB Resume event */
  case CY_U3P_USB_EVENT_RESUME:
    glSuspendEnbl = CyFalse;
    sensor_dbg("USB RESUME event detected\r\n");
    break;

  /* USB Disconnect event. The evData is not used */
  case CY_U3P_USB_EVENT_DISCONNECT:
    sensor_dbg("USB disconnect event detected\r\n");
    CyU3PGpifDisable(CyTrue);
    gpif_initialized = 0;
    isUsbConnected   = CyFalse;
    streamingStarted = CyFalse;
    CyFxUVCApplnAbortHandler();
    if (glIsApplnActive) {
      /* enable USB LPM to receive a USB connect or reset event every time*/
      CyU3PUsbLPMEnable();
      glIsApplnActive = CyFalse;
    }
    break;

  /* Indicates a data underrun error has been detected on one of the USB endpoints.
   * The event data will provide the endpoint number. */
  case CY_U3P_USB_EVENT_EP_UNDERRUN:
    underrunCnt++;
    sensor_err("EP Underrun on %d, totalcnt:%d\r\n", evdata, underrunCnt);
    break;

  /* USB Set Interface event. The evData parameter provides the interface number and the selected
   * alternate setting values.
   * Bits  7 - 0: LSB of wValue field from setup request.
   * Bits 15 - 8: LSB of wIndex field from setup request. */
  case CY_U3P_USB_EVENT_SETINTF:
    sensor_dbg("USB Set Interface event detected\r\n");
    break;

  /* Event notifying completion of the status phase of a control request. This event is only generated
   * for control requests that are handled by the user's application; and not for requests that are
   * handled internally by the USB driver. */
  case CY_U3P_USB_EVENT_EP0_STAT_CPLT:
    // sensor_dbg("USB EP0 STAT CPLT event detected\r\n");
    break;

  /* USB Speed event */
  case CY_U3P_USB_EVENT_SPEED:
    sensor_dbg("USB Speed event detected\r\n");
    break;

  default:
    break;
  }
}
/**
 *  @brief      Callback to handle the USB Setup Requests and UVC Class events.
 *  @param[in]  setupdat0    SETUP Data 0.
 *  @param[in]  setupdat1    SETUP Data 1.
 *  @return     no return.
 */
static CyBool_t UVC_USBSetup_CB(uint32_t setupdat0, uint32_t setupdat1) {
  CyBool_t uvcHandleReq = CyFalse;
  CyU3PReturnStatus_t status = CY_U3P_SUCCESS;

  /* Obtain Request Type and Request */
  bmReqType = (uint8_t)(setupdat0 & CY_FX_USB_SETUP_REQ_TYPE_MASK);
  bRequest  = (uint8_t)((setupdat0 & CY_FX_USB_SETUP_REQ_MASK) >> 8);
  wValue    = (uint16_t)((setupdat0 & CY_FX_USB_SETUP_VALUE_MASK) >> 16);
  wIndex    = (uint16_t)(setupdat1 & CY_FX_USB_SETUP_INDEX_MASK);
  wLength   = (uint16_t)((setupdat1 & CY_FX_USB_SETUP_LENGTH_MASK) >> 16);

  /* Check for UVC Class Requests */
  switch (bmReqType) {
  case CY_FX_USB_UVC_GET_REQ_TYPE:
  case CY_FX_USB_UVC_SET_REQ_TYPE:
    /* UVC Specific requests are handled in the EP0 thread. */
    switch (wIndex & 0xFF) {
    case CY_FX_UVC_CONTROL_INTERFACE: {
      uvcHandleReq = CyTrue;
      status = CyU3PEventSet(&glFxUVCEvent, CY_FX_UVC_VIDEO_CONTROL_REQUEST_EVENT,
                              CYU3P_EVENT_OR);
      if (status != CY_U3P_SUCCESS) {
        sensor_err("Set CY_FX_UVC_VIDEO_CONTROL_REQUEST_EVENT Failed %x\n", status);
        CyU3PUsbStall(0, CyTrue, CyFalse);
      }
    }
    break;

    case CY_FX_UVC_STREAM_INTERFACE: {
      uvcHandleReq = CyTrue;
      status = CyU3PEventSet(&glFxUVCEvent, CY_FX_UVC_VIDEO_STREAM_REQUEST_EVENT,
                              CYU3P_EVENT_OR);
      if (status != CY_U3P_SUCCESS) {
        /* Error handling */
        sensor_err("Set CY_FX_UVC_VIDEO_STREAM_REQUEST_EVENT Failed %x\n", status);
        CyU3PUsbStall(0, CyTrue, CyFalse);
      }
    }
    break;

    default:
      break;
    }
    break;

  case CY_FX_USB_SET_INTF_REQ_TYPE:
    if (bRequest == CY_FX_USB_SET_INTERFACE_REQ) {
      /* MAC OS sends Set Interface Alternate Setting 0 command after
       * stopping to stream. This application needs to stop streaming. */
      if ((wIndex == CY_FX_UVC_STREAM_INTERFACE) && (wValue == 0)) {
        /* Stop GPIF state machine to stop data transfers through FX3 */
        sensor_dbg("Alternate setting 0..\r\n");
        CyU3PGpifDisable(CyTrue);
        gpif_initialized = 0;
        streamingStarted = CyFalse;
        /* Place the EP in NAK mode before cleaning up the pipe. */
        CyU3PUsbSetEpNak(CY_FX_EP_BULK_VIDEO, CyTrue);
        CyU3PBusyWait(100);

        /* Reset and flush the endpoint pipe. */
        CyU3PDmaMultiChannelReset(&glChHandleUVCStream);
        CyU3PUsbFlushEp(CY_FX_EP_BULK_VIDEO);
        CyU3PUsbSetEpNak(CY_FX_EP_BULK_VIDEO, CyFalse);
        CyU3PBusyWait(100);

        /* Clear the stall condition and sequence numbers. */
        CyU3PUsbStall(CY_FX_EP_BULK_VIDEO, CyFalse, CyTrue);
        uvcHandleReq = CyTrue;
        /* Complete Control request handshake */
        CyU3PUsbAckSetup();
        /* Indicate stop streaming to main thread */
        clearFeatureRqtReceived = CyTrue;
        CyFxUVCApplnAbortHandler();
      }
    }
    break;

  case CY_U3P_USB_TARGET_ENDPT:
    if (bRequest == CY_U3P_USB_SC_CLEAR_FEATURE) {
      if (wIndex == CY_FX_EP_BULK_VIDEO) {
        /* Windows OS sends Clear Feature Request after it stops streaming,
         * however MAC OS sends clear feature request right after it sends a
         * Commit -> SET_CUR request. Hence, stop streaming only of streaming
         * has started. */
        if (streamingStarted == CyTrue) {
          sensor_info("Clear feature request detected..\r\n");
          /*free kfifo */
          kfifo_free(&IMU_kfifo);

          /* Disable the GPIF state machine. */
          CyU3PGpifDisable(CyTrue);
          gpif_initialized = 0;
          streamingStarted = CyFalse;

          /* Place the EP in NAK mode before cleaning up the pipe. */
          CyU3PUsbSetEpNak(CY_FX_EP_BULK_VIDEO, CyTrue);
          CyU3PBusyWait(100);

          /* Reset and flush the endpoint pipe. */
          CyU3PDmaMultiChannelReset(&glChHandleUVCStream);
          CyU3PUsbFlushEp(CY_FX_EP_BULK_VIDEO);
          CyU3PUsbSetEpNak(CY_FX_EP_BULK_VIDEO, CyFalse);
          CyU3PBusyWait(100);

          /* Clear the stall condition and sequence numbers. */
          CyU3PUsbStall(CY_FX_EP_BULK_VIDEO, CyFalse, CyTrue);

          uvcHandleReq = CyTrue;
          /* Complete Control request handshake */
          CyU3PUsbAckSetup();
          /* Indicate stop streaming to main thread */
          clearFeatureRqtReceived = CyTrue;
          CyFxUVCApplnAbortHandler();
        } else {
          uvcHandleReq = CyTrue;
          CyU3PUsbAckSetup();
        }
      }
    }
    break;
  default:
    break;
  }
  /* Return status of request handling to the USB driver */
  return uvcHandleReq;
}

/* DMA callback providing notification when each buffer has been sent out to the USB host.
 * This is used to track whether all of the data has been sent out.
 */
void CyFxUvcApplnDmaCallback(CyU3PDmaMultiChannel *multiChHandle, CyU3PDmaCbType_t type,
                              CyU3PDmaCBInput_t *input) {
  if (type == CY_U3P_DMA_CB_CONS_EVENT) {
    consCount++;
    streamingStarted = CyTrue;
  }
}

/**
 *  @brief      .
 *  This function is called from the GPIF callback when we have reached the end of a video frame.
 *  The DMA buffer containing the last part of the frame may not have been committed, and need to
 *  be manually wrapped up. This function uses the current GPIF state ID to identify the socket on
 *  which this last buffer is pending, and then uses the CyU3PDmaMultiChannelSetWrapUp function
 *  to commit the buffer.
 *  @param[in]  handle     Handle to DMA channel.
 *  @param[in]  stateId    Current GPIF state ID.
 *  @return     no return.
 */
static uint8_t CyFxUvcAppCommitEOF(CyU3PDmaMultiChannel *handle, uint8_t stateId) {
  CyU3PReturnStatus_t apiRetStatus = CY_U3P_SUCCESS;
  uint8_t socket = 0xFF;      /*  Invalid value. */

  /* Verify that the current state is a terminal state for the GPIF state machine. */
  switch (stateId) {
  case FULL_BUF_IN_SCK0:
  case FULL_BUF_IN_SCK1:
    /* Buffer is already full and would have been committed. Do nothing. */
    break;
  case PARTIAL_BUF_IN_SCK0:
    socket = 0;
    break;
  case PARTIAL_BUF_IN_SCK1:
    socket = 1;
    break;
  default:
    /* Unexpected current state. Return error. */
    return 1;
  }

  if (socket != 0xFF) {
    /* We have a partial buffer. Commit the buffer manually. The Wrap Up API,
     * here, helps produce a partially filled buffer on the producer side. This
     * action will cause CyU3PDmaMultiChannelGetBuffer API in the UVC_AppThread_Entry
     * function to succeed one more time with less than full producer buffer count */
    apiRetStatus = CyU3PDmaMultiChannelSetWrapUp(handle, socket);
    if (apiRetStatus != CY_U3P_SUCCESS) {
      sensor_err("Channel Set WrapUp failed, Error code = %d\r\n", apiRetStatus);
      CyFxAppErrorHandler(apiRetStatus);
    }
  }

  return 0;
}

/* GpifCB callback function is invoked when FV triggers GPIF interrupt */
void CyFxGpifCB(CyU3PGpifEventType event, uint8_t currentState) {
  if (event == CYU3P_GPIF_EVT_SM_INTERRUPT) {
    // sensor_dbg("CYU3P_GPIF_EVT_SM_INTERRUPT...\r\n");
    hitFV = CyTrue;
    // sensor_info("a frame Transfer prodCount:%d consCount:%d\r\n", prodCount, consCount);
    if (CyFxUvcAppCommitEOF(&glChHandleUVCStream, currentState) != CY_U3P_SUCCESS)
      sensor_err("Commit EOF failed!\n");
  }
}
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
int main(void) {
  CyU3PReturnStatus_t apiRetStatus;

  firmware_ctrl_flag.log_dbg = 1;
  firmware_ctrl_flag.log_info = 1;
  firmware_ctrl_flag.log_dump = 1;
  firmware_ctrl_flag.imu_from_image = 0;
  firmware_ctrl_flag.print_frame_rate = 0;

  debug_level = firmware_ctrl_flag.log_dbg | firmware_ctrl_flag.log_info << 1 \
              | firmware_ctrl_flag.log_dump << 2;

  XPIRLx_IR_ctrl.Set_infrared_mode = 0;
  XPIRLx_IR_ctrl.Set_structured_mode = 0;
  XPIRLx_IR_ctrl.pwm_value = 0;
  XPIRLx_IR_ctrl.RGB_IR_period = 0;
  /* Initialize the device */
  apiRetStatus = CyU3PDeviceInit(0);
  if (apiRetStatus != CY_U3P_SUCCESS) {
    goto handle_fatal_error;
  }

  /* Turn on instruction cache to improve firmware performance.
     Use Release build to improve it further */
  apiRetStatus = CyU3PDeviceCacheControl(CyTrue, CyFalse, CyFalse);

  /* IO matrix configure */
  fx3_IO_matrix_config();

  /* This is a non returnable call for initializing the RTOS kernel */
  CyU3PKernelEntry();
  /* Dummy return to make the compiler happy */
  return 0;

handle_fatal_error:
  /* Cannot recover from this error. */
  while (1);
}

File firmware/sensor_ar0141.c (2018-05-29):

/******************************************************************************
 * Copyright 2017-2018 Baidu Robotic Vision Authors. All Rights Reserved.
 *
 * Licensed under the Apache License, Version 2.0 (the "License");
 * you may not use this file except in compliance with the License.
 * You may obtain a copy of the License at
 *
 * http://www.apache.org/licenses/LICENSE-2.0
 *
 * Unless required by applicable law or agreed to in writing, software
 * distributed under the License is distributed on an "AS IS" BASIS,
 * WITHOUT WARRANTIES OR CONDITIONS OF ANY KIND, either express or implied.
 * See the License for the specific language governing permissions and
 * limitations under the License.
 *****************************************************************************/

#include <cyu3system.h>
#include <cyu3os.h>
#include <cyu3dma.h>
#include <cyu3error.h>
#include <cyu3uart.h>
#include <cyu3i2c.h>
#include <cyu3types.h>
#include <cyu3gpio.h>
#include "include/sensor_ar0141.h"
#include "include/sensor_v034_raw.h"
#include "include/debug.h"
#include "include/fx3_bsp.h"
// AR0141 register address map
// Frame rate Fps = 1/Tframe
// Tframe = 1 /(CLK_PIX) * [frame_length_lines * line_length_pck + extra_delay]
// Minimumframe_length_lines = (y_addr_end - y_addr_start + 1) /
//                             ((y_odd_inc + 1) / 2) + min_vertical_blanking
// TODO(zhoury): max frame rate is 23Hz at 27MHz
#define CLK_PIX            27000000
#define FRAME_FPS          25
#define FRAME_LENGTH_LINES 750    // defalut: 750(0x02EE)  0x00E2=226 0x05DC=1500
#define EXTRA_DELAY        0
#define LINE_LENGTH_PCK    ((CLK_PIX / FRAME_FPS -  EXTRA_DELAY)/ FRAME_LENGTH_LINES)

// Exposure/Integration register
#define COARSE_INTEGRATION_TIME       300  // default:16(0X0010)
#define FINE_INTEGRATION_TIME         0       // default:0

#define FLASH_CONTROL         0x0038
#define FLASH_PERIODS         0xFFFF
#define GRR_CONTROL1          0x0081
// Gain relative register
// The digital channel gain format is xxxx.yyyyyyy where
// xxxx refers integer gain of 1 -15
// yyyyyyy refer to fractional gain from 0/128 to 127/128
#define GREEN1_INTEGER        1
#define GREEN1_FRACTIONAL     0
#define GREEN1_GAIN           (GREEN1_INTEGER << 7 | GREEN1_FRACTIONAL)  // default:128(0X80)
#define BLUE_INTEGER          1
#define BLUE_FRACTIONAL       56
#define BLUE_GAIN             (BLUE_INTEGER << 7 | BLUE_FRACTIONAL)      // default:128(0X80)
#define RED_INTEGER           1
#define RED_FRACTIONAL        56
#define RED_GAIN              (RED_INTEGER << 7 | RED_FRACTIONAL)        // default:128(0X80)
#define GREEN2_INTEGER        1
#define GREEN2_FRACTIONAL     0
#define GREEN2_GAIN           (GREEN2_INTEGER << 7 | GREEN2_FRACTIONAL)  // default:128(0X80)
#define GLOBAL_INTEGER        1
#define GLOBAL_FRACTIONAL     0
#define GLOBAL_GAIN           (GLOBAL_INTEGER << 7 | GLOBAL_FRACTIONAL)
// 2^coarse_gain * (1 + fine_gain/16)
#define COARSE_GAIN           0
#define FINE_GAIN             14
#define ANALOG_GAIN           (COARSE_GAIN << 4 | FINE_GAIN)

#define AR0141_WINDOW_X_MAX    1344
#define AR0141_WINDOW_Y_MAX    848
#define AR0141_IMG_WIDTH       1280   // x
#define AR0141_IMG_HEIGHT      720    // y

#define AR0141_X_ADDR_START    ((AR0141_WINDOW_X_MAX - AR0141_IMG_WIDTH) / 2)
#define AR0141_X_ADDR_END      (AR0141_X_ADDR_START + AR0141_IMG_WIDTH - 1)
#define AR0141_Y_ADDR_START    ((AR0141_WINDOW_Y_MAX - AR0141_IMG_HEIGHT) / 2)
#define AR0141_Y_ADDR_END      (AR0141_Y_ADDR_START + AR0141_IMG_HEIGHT - 1)

uint16_t AR0141_Parallel_seq[] = {
  0x3088, 0x8000,
  0x3086, 0x4558,
  0x3086, 0x6E9B,
  0x3086, 0x4A31,
  0x3086, 0x4342,
  0x3086, 0x8E03,
  0x3086, 0x2714,
  0x3086, 0x4578,
  0x3086, 0x7B3D,
  0x3086, 0xFF3D,
  0x3086, 0xFF3D,
  0x3086, 0xEA27,
  0x3086, 0x043D,
  0x3086, 0x1027,
  0x3086, 0x0527,
  0x3086, 0x1535,
  0x3086, 0x2705,
  0x3086, 0x3D10,
  0x3086, 0x4558,
  0x3086, 0x2704,
  0x3086, 0x2714,
  0x3086, 0x3DFF,
  0x3086, 0x3DFF,
  0x3086, 0x3DEA,
  0x3086, 0x2704,
  0x3086, 0x6227,
  0x3086, 0x288E,
  0x3086, 0x0036,
  0x3086, 0x2708,
  0x3086, 0x3D64,
  0x3086, 0x7A3D,
  0x3086, 0x0444,
  0x3086, 0x2C4B,
  0x3086, 0x8F01,
  0x3086, 0x4372,
  0x3086, 0x719F,
  0x3086, 0x4643,
  0x3086, 0x166F,
  0x3086, 0x9F92,
  0x3086, 0x1244,
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
};

uint16_t AR0141_Parallel_init[] = {
  0x301A, 0x10D8,  // RESET_REGISTER = 4312
  0x302A, 0x0009,  // VT_PIX_CLK_DIV = 6       default: 6    Range: 4-16
  0x302C, 0x0001,  // VT_SYS_CLK_DIV = 1       Range: 1,2,4,6,8,10,11,12,14,16
  0x302E, 0x0003,  // PRE_PLL_CLK_DIV = 3      default: 4 Range: 1-64
  0x3030, 0x001B,  // PLL_MULTIPLIER = 27      default: 66 Range: 32-384
  0x3036, 0x000C,  // OP_PIX_CLK_DIV = 12
  0x3038, 0x0002,  // OP_SYS_CLK_DIV = 2

  0x31AC, 0x0C0C,  // DATA_FORMAT_BITS = 3084
  0x31AE, 0x0301,  // SERIAL_FORMAT = 769
  0x30B0, 0x4000,  // DIGITAL_TEST = 0
  0x30BA, 0x002C,  // DIGITAL_CTRL = 300
  0x3002, AR0141_Y_ADDR_START,  // Y_ADDR_START  default: 64(0x0040)
  0x3004, AR0141_X_ADDR_START,  // X_ADDR_START  default: 18(0x0012)
  0x3006, AR0141_Y_ADDR_END,    // Y_ADDR_END    defalut: 791(0x0317)  0x01DF=479 0x02CF=719
  0x3008, AR0141_X_ADDR_END,    // X_ADDR_END    defalut: 1305(0x0519) 0x027F=639 0x04FF=1279
  0x300A, FRAME_LENGTH_LINES,  // FRAME_LENGTH_LINES
  0x300C, LINE_LENGTH_PCK,  // LINE_LENGTH_PCK
  0x3042, EXTRA_DELAY,  // EXTRA_DELAY

  0x3012, COARSE_INTEGRATION_TIME,  // COARSE_INTEGRATION_TIME
  0x3014, FINE_INTEGRATION_TIME,   // FINE_INTEGRATION_TIME
  0x3046, FLASH_CONTROL,  // FLASH_CONTROL
  0x3048, FLASH_PERIODS,  // FLASH_PERIODS
  0x30DA, 0x00FF,  // FLASH_PERIODS
  // disable embedded data
  0x3056, GREEN1_GAIN,  // GREEN1_GAIN   defalut: 128(0x0080)
  0x3058, BLUE_GAIN,    // BLUE_GAIN     defalut: 128(0x0080)
  0x305A, RED_GAIN,     // RED_GAIN      defalut: 128(0x0080)
  0x305C, GREEN2_GAIN,  // GREEN2_GAIN   defalut: 128(0x0080)
  // 0x305E, GLOBAL_GAIN,  // GLOBAL_GAIN   defalut: 128(0x0080)
  0x3060, ANALOG_GAIN,  // ANALOG_GAIN   defalut: 0(0x0000)
  0x3064, 0x1802,  // SMIA_TEST
  0x30A2, 0x0001,  // X_ODD_INC = 1
  0x30A6, 0x0001,  // Y_ODD_INC = 1
  0x3082, 0x000D,  // OPERATION_MODE_CTRL = 1
  0x3084, 0x000D,  // OPERATION_MODE_CTRL_CB = 1
  0x308C, 0x00B8,  // Y_ADDR_START_CB = 6
  0x308A, 0x0160,  // X_ADDR_START_CB = 24
  0x3090, 0x0290,  // Y_ADDR_END_CB = 847
  0x308E, 0x03DF,  // X_ADDR_END_CB = 1319
  0x30AA, 0x01ED,  // FRAME_LENGTH_LINES_CB = 1500
  0x303E, 0x13A1,  // LINE_LENGTH_PCK_CB = 1650
  0x3016, 0x000E,  // COARSE_INTEGRATION_TIME_CB = 45
  0x30AE, 0x0001,  // X_ODD_INC_CB = 1
  0x30A8, 0x0001,  // Y_ODD_INC_CB = 1
  0x3040, 0x0000,  // READ_MODE = 0
  // 0x30CE, GRR_CONTROL1,  // GRR_CONTROL1
  0x318E, 0x0000,  // HDR_MC_CTRL3 = 0
  0x3100, 0x0004,
  0x301A, 0x10D8   // RESET_REGISTER = 4316
};
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

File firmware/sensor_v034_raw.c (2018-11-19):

/******************************************************************************
 * Copyright 2017-2018 Baidu Robotic Vision Authors. All Rights Reserved.
 *
 * Licensed under the Apache License, Version 2.0 (the "License");
 * you may not use this file except in compliance with the License.
 * You may obtain a copy of the License at
 *
 * http://www.apache.org/licenses/LICENSE-2.0
 *
 * Unless required by applicable law or agreed to in writing, software
 * distributed under the License is distributed on an "AS IS" BASIS,
 * WITHOUT WARRANTIES OR CONDITIONS OF ANY KIND, either express or implied.
 * See the License for the specific language governing permissions and
 * limitations under the License.
 *****************************************************************************/

#include <cyu3system.h>
#include <cyu3os.h>
#include <cyu3dma.h>
#include <cyu3error.h>
#include <cyu3uart.h>
#include <cyu3i2c.h>
#include <cyu3types.h>
#include <cyu3gpio.h>
#include "include/sensor_v034_raw.h"
#include "include/fx3_bsp.h"
#include "include/debug.h"
#include "include/uvc.h"
/*****************************************************************************
**                               Global data & Function declaration
******************************************************************************/

static BYTE Buf[2];
uint8_t AE_MODE_CUR = 0;
// #define SENSOR_GAIN_CHECK

static void V034_ChipID_Check(uint8_t SlaveAddr);
void DRV_imgsSetRegs(void);
/*****************************************************************************
**                                  Function definition
******************************************************************************/
/* V034,reg address 8 bits,data 16bits */
CyU3PReturnStatus_t V034_SensorWrite2B(uint8_t SlaveAddr, uint8_t HighAddr,
                                       uint8_t LowAddr, uint8_t HighData, uint8_t LowData) {
  CyU3PReturnStatus_t apiRetStatus = CY_U3P_SUCCESS;
  CyU3PI2cPreamble_t preamble;
  uint8_t Buf[2];

  if (SlaveAddr != L_SENSOR_ADDR_WR && SlaveAddr != R_SENSOR_ADDR_WR) {
    sensor_err("I2C Slave address is not valid!\r\n");
    return 1;
  }

  preamble.buffer[1] = LowAddr;
  preamble.buffer[0] = SlaveAddr; /* Slave address: Write operation */
  preamble.length = 2;
  preamble.ctrlMask = 0x0000;
  Buf[0] = HighData;
  Buf[1] = LowData;
  apiRetStatus = CyU3PI2cTransmitBytes(&preamble, Buf, 2, 0);
  if (apiRetStatus == CY_U3P_SUCCESS) {
    V034_delay(800);  /* known issue for SDK I2C */
  } else {
    sensor_err("W2B I2C write error\r\n");
  }
  return apiRetStatus;
}
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

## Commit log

2017-11-15 boteye_sensor coming live!
    [XPCAM 1V1 PCB BOM.xls, XPCAM-C 1V4 PCB BOM.xls, XPCAM-C_1V4.PCBDOC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]
2017-12-26 New version update
    [XPCAM 1V1 PCB BOM.xls, XPCAM-C 1V4 PCB BOM.xls, XPCAM-C_1V4.PCBDOC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]
2018-02-09 Boteye sensor upgrade
